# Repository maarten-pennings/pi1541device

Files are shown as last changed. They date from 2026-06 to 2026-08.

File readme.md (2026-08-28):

# Pi1541

My take on the _Pi1541_, the cycle exact Commodore 1541 disk drive emulator that runs on a Raspberry Pi.

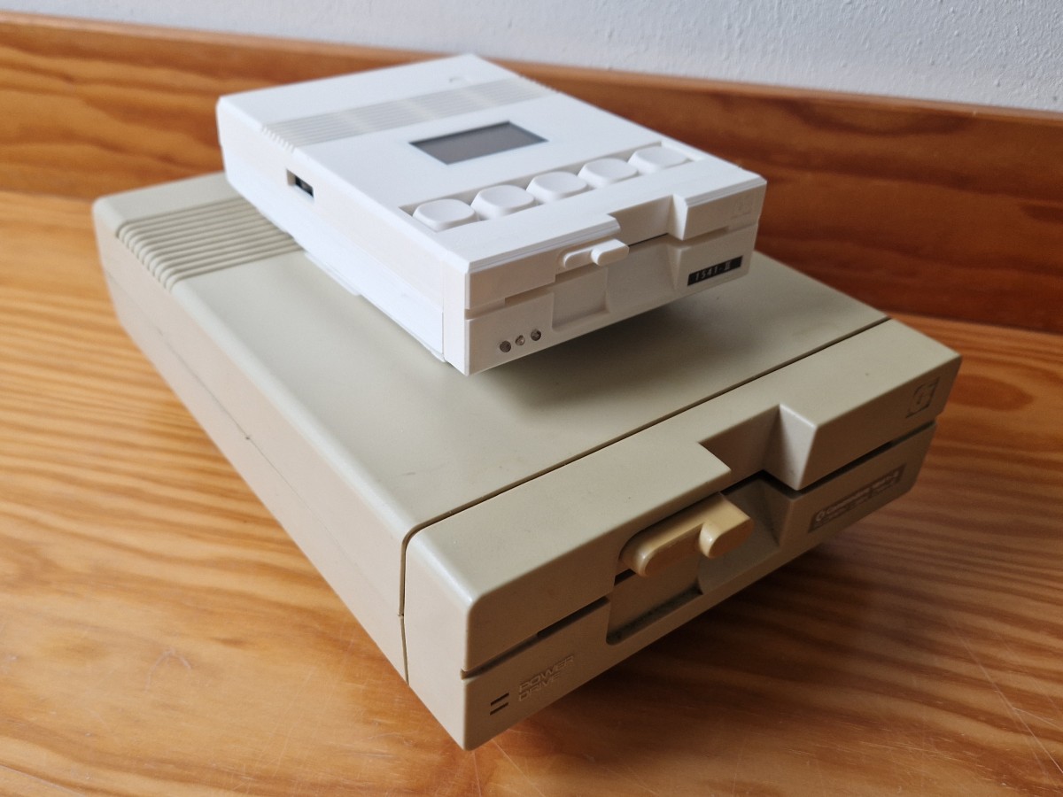
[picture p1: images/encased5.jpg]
My Pi1541 on top of an original
> 
> _My Commodore 1541-II disk drive (bottom) with my Pi1541 replica on top._

## Introduction

The _Commodore 1541_ is a 5.25-inch floppy disk drive.
It was _the_ solution for file storage when working with Commodore 64 (C64). 
Over the decades the drives and floppy disks degraded.
Various disk drive replacements where developed. 
One of them is the _Pi1541_, the topic of this repo.

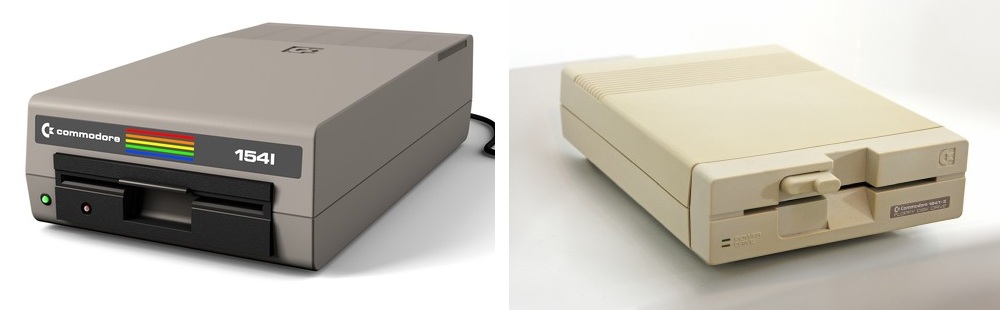
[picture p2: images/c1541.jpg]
C1541
> 
>
> _Commodore 1541 from [Commodore online museum](https://cbmmuseum.kuto.de/floppy_vc1541.html)_
> _and later model (1541-ii) from [Wikipedia](https://en.wikipedia.org/wiki/Commodore_1541)_

An important predecessors of the Pi1541 was the 
[SD2IEC](https://www.c64-wiki.com/wiki/SD2IEC). The SD2IEC 
contains an ATmega644 micro controller from Atmel that 
translates Commodore serial bus (IEC) commands into FAT 
file system operations on the SD card. This allows the C64 
to access files on an SD card.

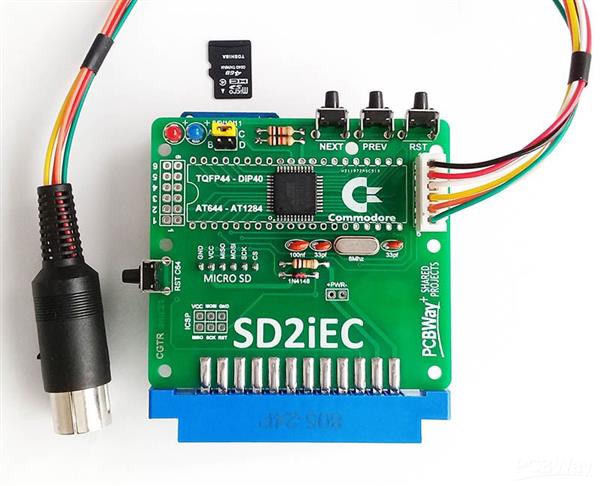
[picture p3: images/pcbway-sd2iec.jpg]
SD2IEC
> 
>
> _Example SD2IEC project from [PCBWAY](https://www.pcbway.com/project/shareproject/SD2iEC_COMMODORE_64_DISK_DRIVE_EMULATOR_POWERED_from_USER_PORT_MICRO_SD_VERSI_c56a9f83.html)_

The SD2IEC is low-cost and capable of storing about 25000 floppies
(of 170 kByte each) on a 4GB SD card. It is small and can be powered 
by the C64 itself (usually via the user port). 
The big drawback is that while the SD2IEC is compatible
with the _file level commands_, it cannot handle the _programming commands_ 
given via the secondary channel 15.

Unfortunately, due to the low-speed of the 1541, many commercial games, demos, 
and developer cartridges come with their own fast loaders. Part of a fast loader 
is software that is uploaded to the 1541 drive (which is a 6502 based 
computer on its own) via the above mentioned programming commands. 
The SD2IEC cannot run that uploaded software.
This results in low software compatibility: a large portion of the C64 
applications (games) will not load from an SD2IEC.

The Pi1541, developed by Steve White, solves this. Instead of an _ATmega644_ micro 
controller, it uses a more powerful _Raspberry Pi_ and a simple add-on (a so-called "HAT"). 
The Pi is powerful enough to provide a cycle-exact hardware emulation of the real 
Commodore 1541 drive. It emulates the drive's internal 6502 CPU, the RAM, 
and the VIA chips down to the exact clock cycle. You even need to download the 
original Commodore ROM image of the 1541 to "program" this virtual 6502.

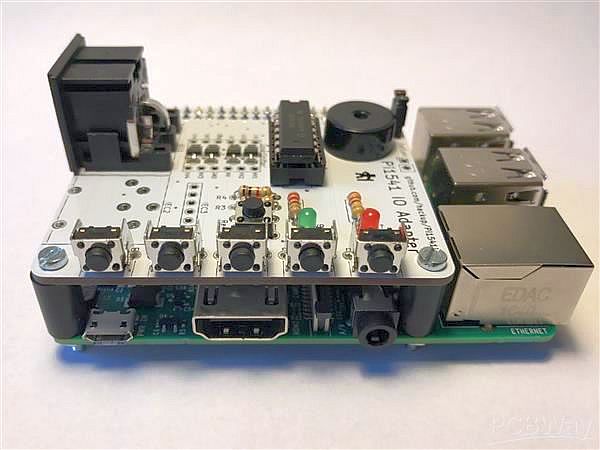
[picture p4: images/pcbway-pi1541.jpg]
Pi1541
> 
>
> _Example Pi1541 project from [PCBWAY](https://www.pcbway.com/project/shareproject/Pi1541_IO_Adapter__Rev_2.html)_

This solution provides near 100% compatibility because it behaves exactly 
like the original drive. It supports complex copy protections and almost every 
fast loader ever written (e.g., JiffyDOS, Final Cartridge III).

Steve White wrote a "bare metal" application on the Pi. This means his 
emulator does not run under Raspberry Pi OS (Linux) but directly on the 
_Broadcom BCM2837B0_. This results in fast booting, and carefree switching off 
the power. On the down side, the Pi1541 is more expensive than the SD2IEC due to the 
Raspberry Pi board; it is a bit bigger physically; and needs (more) external power.
But most believe these down sides are well compensated by the extra compatibility.

## Concepts

This section explains the key concepts when working with the Pi1541: 
current working directory, three categories of commands, the new `CD` command, 
mounting a `.d64` file as virtual floppy, the problem with the programming commands, 
and finally _browse mode_ and _emulation mode_.

### Current working directory

The Pi1541 contains an SD card, and it maintains a notion of the 
_current working directory_ on that SD card. Its firmware bridges the 
commands that come from the C64 (over the IEC bus) to the FAT file system 
on the SD card. 

It does understand the _high level commands_ such as 
`SAVE "MYGAME"`, `LOAD "MYGAME"`, or `LOAD "$"`. The `SAVE "MYGAME"` creates a file `MYGAME` 
on the SD card, in the current working directory. Similarly `LOAD "MYGAME"` 
reads the file `MYGAME` from the current working directory and sends it back 
to the C64 over the IEC bus. It will be no surprise that `LOAD "$"` reads 
the current working directory and sends that back to the C64.

### Commands 

If you are more than a casual user of the C64 and the 1541 drive, 
you will know that next to those high level commands there are more 
_advanced commands_ that a 1541 will understand. 
The Pi1541 also emulates those. For example `OPEN 1,8,15,"S0:MYGAME":CLOSE 1` 
scratches (deletes) the file `MYGAME` from the current working directory, 
and `OPEN 1,8,15,"R0:YOURGAME=MYGAME":CLOSE 1` renames `MYGAME` to `YOURGAME`.

Recall that the DOS (disk operating system) was not part of the C64 
(would have taken too much memory), rather it was baked into the 1541 itself.
What is part of the C64, is setting up a "data pipe" (open a file) and send 
the (textual) command over that pipe. The 1541 receives the textual command,
parses it and executes it. That is the reason we have advanced commands 
(eg see [c64-wiki](https://www.c64-wiki.com/wiki/Commodore_1541#Disk_Drive_Commands)).

### CD 

You might be wondering how to _change_ the current working directory. 
The developers of the SD2IEC added an advanced command: `CD`. For example 
`OPEN 1,8,15,"CD:SUBDIR":CLOSE 1` changes the current working directory 
to subdirectory `SUBDIR` assuming that subdirectory exists in the current 
working directory. The command `OPEN 1,8,15,"CD:←":CLOSE 1` (the `←` being 
the key in the upper left corner on the C64 keyboard) moves back to the 
parent directory. No idea why they did not pick the standard `..` instead 
of the rather obscure `←`. Next to `CD`, related advanced commands were 
added: `MD` to make a directory and `RD` to remove an (empty) directory.

Of course the C64 doesn't know about the `CD` command, but you as operator 
can issue it and the new directory feels like a new disk to the C64. 
Typically the SD2IEC and the Pi1541 also come with a file browser (`FB64`) running on the C64. 
This browser does know the `CD` command and allows easy navigation through 
the file system on the SD card.

### Mounting a virtual floppy 

There is one more important concept. In the C64 retro community, floppy disks are ripped 
to a single file. They have the extension `.d64` and are useable as virtual disk in tools 
like VICE, the C64 Ultimate, and also the SD2IEC and Pi1541. 

SD2IEC and Pi1541 treat `.d64` files a bit like 
Windows treats `.zip` files. It is one _file_, but you can `CD` 
into it, and that "unzipped" `.d64` file is then the "mounted" _directory_. All 
high level commands (`LOAD`) work on the mounted floppy, and so do all 
advanced commands (`S0:MYGAME`). Even `OPEN 1,8,15,"CD:←":CLOSE 1` works;
it unmounts the `.d64` virtual floppy and switches to its parent directory.
Of course `OPEN 1,8,15,"CD:SUBDIR":CLOSE 1` does not work in the mounted `.d64` because
`.d64` files are supposed to be ripped 1541 disks, and the 1541 did not have a notion 
of subdirectories.

### Programming commands 

We should realize that the firmware (of SD2IEC and Pi1541) sees the high 
level and advanced commands come in via the IEC bus. It needs to parse and 
understand the commands, and then execute them. That is the task for the software written 
by the programmers of those two devices. That is development work.

Unfortunately, next to the high level and advanced commands there is a third 
category, the _programming commands_. Chapter 8 of the 1541 
[user manual](https://www.zimmers.net/anonftp/pub/cbm/manuals/drives/1541_Users_Guide.pdf) 
introduces these with the text "The expert programmer can actually design routines 
that reside and operate on the disk controller". This is with commands such as `M-W` 
(memory write), `M-R` (memory read), and `M-E` (memory execute). Here is 
an example from the manual (recall that `RTS` has opcode 0x60 or 96 decimal).

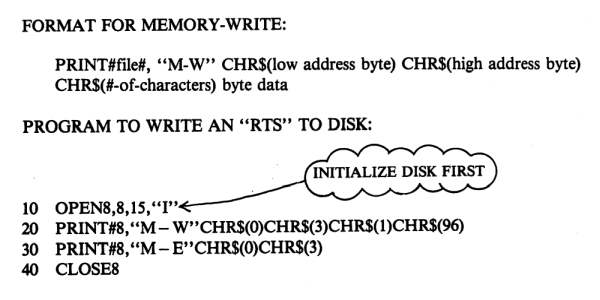
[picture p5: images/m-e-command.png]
memory execute example
> 
>
> _Example of programming commands from the 
> [user manual](https://www.zimmers.net/anonftp/pub/cbm/manuals/drives/1541_Users_Guide.pdf)_

The above 1-byte "program" is written by the C64 into the memory of the 1541 drive 
(to address 0x0300), and then the C64 gives a command to execute from 0x0300. The 1541 
starts executing there, finds opcode 96 (RTS), returns, and stops executing the 
program. I made a more elaborate example 
[blinky1541](https://github.com/maarten-pennings/C64howto/tree/main/blinky1541).
Anyhow, these programming commands of the 1541 are the mechanism used by fast loaders.

### Browse mode versus emulation mode

So far SD2IEC and Pi1541 are very similar. Now we come to an important difference.
The SD2IEC does _not_ implement the programming commands, but Pi1541 _does_.
In a clever way.

The Pi1541 has two modes. The developer, Steve White, calls them _browse mode_ and
_emulation mode_. We could say that the SD2IEC only supports browse mode, and Pi1541 
supports both. When the Pi1541 starts, it is in browse mode. In browse mode, the 
firmware from Steve runs. This firmware implements the high level and advanced 
commands _including the `CD` command_. This allows all existing tools to 
browse all files on the SD card. As soon as a command comes in that `CD`s into 
a virtual floppy disk (a `.d64` file) - I called this "mounting the floppy" above - the Pi1541 
switches to emulation mode. In emulation mode the Raspberry Pi _emulates the 1541_.

The emulation is serious. A real 1541 contains a 6502,
RAM, ROM, and VIAs. The Pi1541 emulates all of those, to the clock cycle. 
Timing of pulses on the IEC bus matters to the C64. What code does the emulated 
6502 run? It runs the original 1541 ROM from Commodore that you have to download 
and put on the SD card - Steve can't do that due to licensing reasons. As a consequence 
all `M-W` and `M-E` commands are working since they are implemented by that 1541 rom. 
Software that is uploaded and executed this way, by the fast loaders, also just works; 
it doesn't know the 1541 is emulated.

In emulation mode, an `OPEN 1,8,15,"CD:←":CLOSE 1` is intercepted, unmounts the `.d64`, 
sets the working directory to the parent, and switches back to browse mode. 

It is important for a user to know about these two modes, and to know which one is 
running when. For example, the advanced command `OPEN 1,8,15,"N0:DISKNAME,DN":CLOSE 1`
(recall `N` stands for `NEW` meaning "format") in _browse_ mode just _creates_ a 
new, empty, formatted virtual floppy image with the name `DISKNAME.d64` on the SD card. 
If you give the same command in emulation mode, the original 1541 firmware kicks in, 
and it will happily wipe (format) the entire mounted `.d64` virtual floppy.

> There is another, arguably more important, caveat to be aware of. 
> Writes to a .d64 image (e.g. `SAVE "MYPROG"`) in emulation mode are not 
> written-through to the SD card. All updates are in the Pi's RAM. 
> You _must unmount_ the virtual floppy (with `"CD:←"` or by pressing 
> the ESC key on the Pi1541). Only then the new content is written to 
> the FAT file system on the SD card.

### My additions

Mostly for fun, I have made a couple of additions to Steve's firmware. The `CD:subdir` command 
goes one subdirectory down, and `CD:←` goes one up. For some reason the `CD://` did not 
work. It is supposed to go to the root directory (yes with two slashes, something to 
do with multiple volumes). I fixed it. Secondly, I was missing a `pwd` command (print 
working directory). I added a `LOAD "$$"` command (I call it "sysinfo") that does that. 
I added both features in 
[v1.27](https://github.com/maarten-pennings/Pi1541#additions-in-this-fork).

## Real life operation

You might be wondering how the Pi1541 works in real life. 

You can operate the device completely from the C64:
you can do the `CD` commands combined with `LOAD "$"` by hand,
or let `FB64` do them for you.

But the Raspberry Pi can also be connected to a full keyboard and HDMI screen. 
The HDMI screen will always show the current directory and its contents (files and 
subdirectories), also when it is changed with `CD` (or `FB64` doing `CD`s).
It is also possible to change the current directory with a keyboard 
connected to the Raspberry Pi (via USB). 

There is a third option. We can connect an OLED and five buttons 
(Next, Previous, Select, Escape and Insert) to the Pi. 
The OLED will also always show the current directory 
(in sync with the HDMI screen), and the buttons also allow browsing 
(just like the USB keyboard).

Three methods, always in sync.

Oh, and in [v1.25](https://github.com/maarten-pennings/Pi1541#additions-in-this-fork)
I added support for a bigger (1.54") OLED, making it easier to read from a distance.

The table below shows the functions of the five buttons. 
When holding the Insert key for a longer time, it acts as a shift key for the 
other four. It changes the device number as shown in the "Drive" column.
The swaplist is there to support large programs that use multiple floppies 
that need to be swapped during the run-time of the program.
Finally, note that the Escape key triggering an unmount is a feature of my v1.27 firmware;
originally Select did the unmount.

| Button | Description | Browse mode | Emulation mode |Drive |
|:---|:---|:---|:---|:----:|
| SEL | Select | Change to sub dir (or mount) | - | 8 |
| PRV | Previous | Select previous dir | Previous in swaplist | 9 |
| NXT | Next | Select next dir | Next in swaplist | 10 |
| ESC | Escape | Change to parent dir | Unmount | 11 |
| INS | Insert | Insert .d64 file in swaplist | - | shift|

## SD card

Preparing the SD card for the Raspberry Pi means merging files from different sources.

There are three sources:

- The GitHub repo from the Raspberry Pi foundation supplies the Pi's bootloader files.
- The GitHub repo from Steve (or me) supplies the Pi1541 firmware and its config file (and a filebrowser)
- Some internet site supplies the Commodore 1541-II firmware and the C64 font roms (used on the OLED), and maybe the game _Ghosts'n Goblins Arcade_ to test the hex inverter quality.

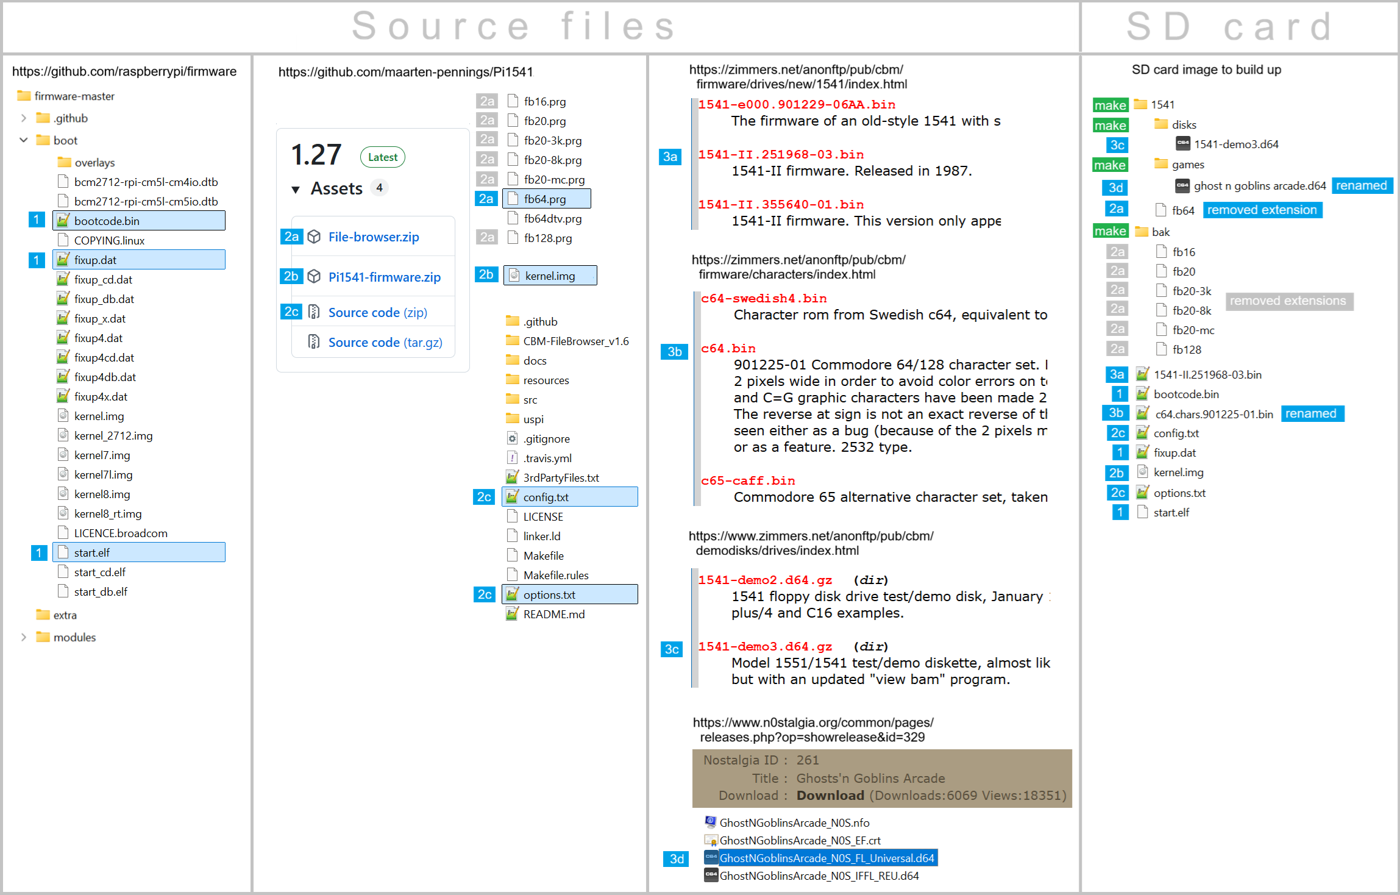
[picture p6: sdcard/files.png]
sdcard creation
> 
> _The three sources of files to be combined into the SD card image._

This repo includes a prepackaged [SD card image](sdcard/pi1541sdcard.zip).
Alternatively, check the [sdcard](sdcard) subdirectory for a do-it-yourself 
and some technical background details.

Note that a `.prg` file in a sub directory (not inside a `.d64`) 
will typically be loaded with a `LOAD` command passing the _filename_ as 
used on the SD card. It is advised to restrict the filename to
characters available on the C64, e.g. no `_`, but also no _capitals_.
Personally, I also leave out the `.prg` extension; 
`LOAD "HELLO",8` feels more C64 like than `LOAD "HELLO.PRG",8`.
Similar considerations (uppercase, underscores) apply to naming subdirectories.

## My design

I wanted a Pi1541 for my C64.
My goal was to make a device that resembles a real drive.

I wanted it fully featured: local keys and display, two IEC connectors 
(daisy chainable IEC like the real drives), physical access to the SD card, a reset button, 
power and activity LED, an LED to show data line status, drive sound emulation,
access for USB power and access to HDMI out. 

I wanted it easy to operate: 
big buttons ([Cherry keys](https://nl.aliexpress.com/item/1005012280948086.html)), 
big display (biggest OLED). I wanted the replica to roughly have the same aspect ratios as the original 
drive (the 1541-II is 240×180×70 mm³). This posed a problem for the Cherry keys; 
they are relatively tall, so they need to be mounted on the "floor" PCB,
the PCB that I had to design. 

My PCB would normally be the HAT ("Hardware Attached on Top") for the Raspberry Pi,
but due to the Cherry keys I needed to turn them upside down. My PCB is 
the HAB ("Hardware Attached on Bottom") which holds the Cherry keys and the IEC
connectors, and the Pi, upside down. I did want an (OLED) display, 
so that needed to be above the Pi.

This is a sketch of how I envisioned the topology.

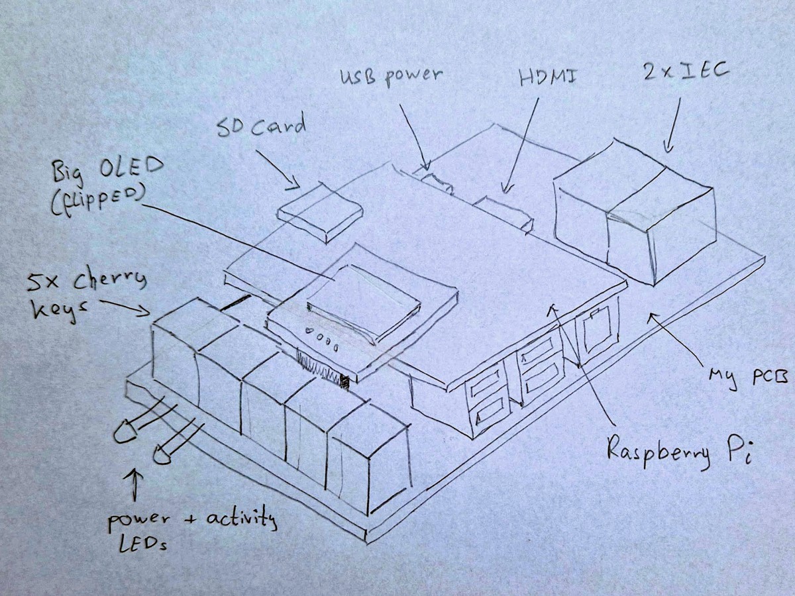
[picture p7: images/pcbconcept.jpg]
Pi1541 concept sketch
> 
> _Sketching the placement of the key components_

From front to back we find:

- LEDs on the front (for the front panel).
- Next the Cherry keys on floor PCB.
- High rising pin header for a flipped OLED,  
  flipped in the sense that the top pixel row of the OLED is now facing the Cherry keys.
- After that we have the upside-down Raspberry Pi, SD card nicely accessible from the side.
- At the back we have the two IEC DIN connectors also on the floor PCB.
- Biggest problem is that the power (and HDMI) are not flush with the backside.
  I mitigated that by using an 
  [USB-C to micro USB converter](https://nl.aliexpress.com/item/1005009140380972.html), 
  which not only converts to the newer USB-C, it also happens to bring the USB connector 
  more to the back.

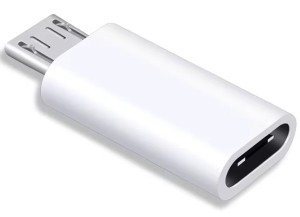
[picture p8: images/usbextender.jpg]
USB extender
> 
> _USB-C to micro USB converter_

### Hardware

The simplest schematics Steve White offers is a Raspberry Pi and a level shifter
("Option A"). I based my design on [Option B](https://cbm-pi1541.firebaseapp.com/#:~:text=are%20all%20optional.-,Option%20B,-This%20option%20uses) of Steve.
This is for devices with two IECs. The Pi is not capable of sourcing enough current
for the second "outgoing" IEC bus, so a tri-state hex inverter IC (7406) 
is used as bus driver. Steve warns that this driver IC needs to be selected carefully.

> [Ghosts'n Goblins Arcade](https://www.n0stalgia.org/common/pages/releases.php?op=showrelease&id=329) 
> can be used to test the capability of your hex inverter.
> If the title screen is corrupt then please substitute the hex inverter IC for a genuine branded version.

It was a bit of a puzzle how to connect the peripherals to the Pi.
The IEC wiring is different between Option A and B.
The local buttons, activity LED and buzzer are shown in Steve's schematics, but not the OLED.
I started with a breadboard.

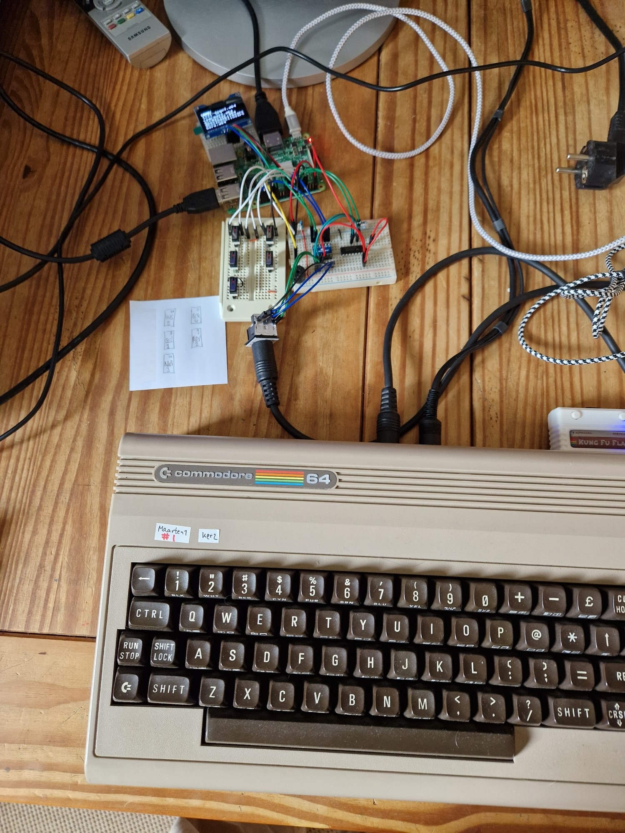
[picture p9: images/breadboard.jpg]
Breadboard
> 
> _Option B prototype on a breadboard_

I used the biggest 128×64 OLED module I had in stock.
It is [1.54 inch](https://nl.aliexpress.com/item/1005006579037427.html), not the more
common 1.3" neither the even smaller 0.96".
Since the various OLEDs modules tend to vary in the order of the four pins (SCL, SDA, VCC, GND), 
I added a second header (J3 and J4) and solder jumpers in between.
This allows me to solder patch wires if I have an OLED with different pin order.

I did add a (RESET) button on the IEC reset line. Pressing it resets the Pi1541 as well 
as the C64. Not sure if that is useful. I considered, but did not add 
a button that resets just the Pi; the Pi does have two pads for that.

I did add a beeper. 
I believe I have a [passive](https://www.circuitbasics.com/what-is-a-buzzer/) one.
These require a waveform to be generated by the micro controller (Pi in my case);
they are low end "speakers for audio". Active beepers on the other hand only need power;
they have a built-in oscillator and produce single frequency beeps.
Warning: the emulated drive sound is much lower quality then what VICE offers; 
I believe it is basically a buzz when the drive head moves a track.

I added a red LED for power and green for the activity LED.
This is the color scheme used in the 1541-II. The original 1541 had the colors swapped.

> The latest firmware (1.24) of Steve has a regression: the Activity LED is not working.
> I fixed that in my [fork](https://github.com/maarten-pennings/Pi1541).

My final addition was a blue LED that is on the IEC _data_ line.
We see it flicker when data is transmitted.

I ordered my PCBs at [JLCPCB](https://jlcpcb.com/DMP); 5 PCBs for €10.44 including 
shipping, arrived in 10 days.

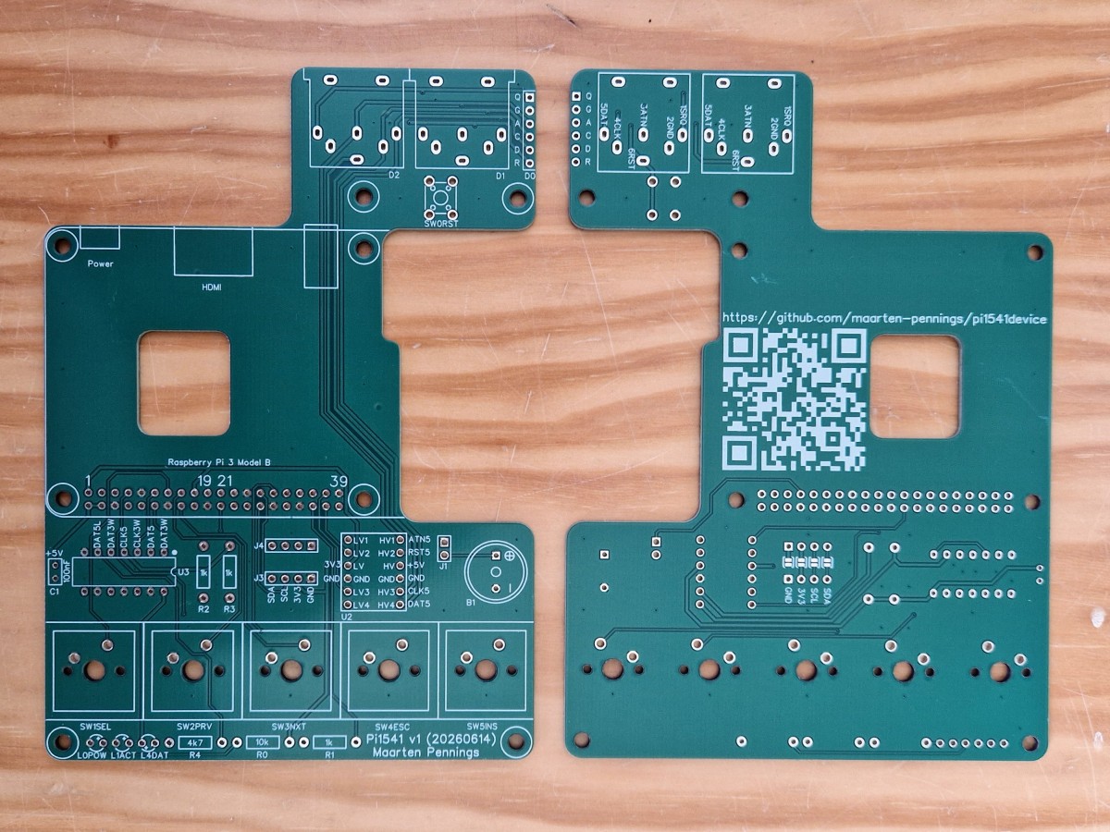
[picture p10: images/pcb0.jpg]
PCB front and back
> 
> _Bare PCB (front and back)_

A photo of the assembled PCB, including some 3D printed parts like the OLED holder
and standoffs.

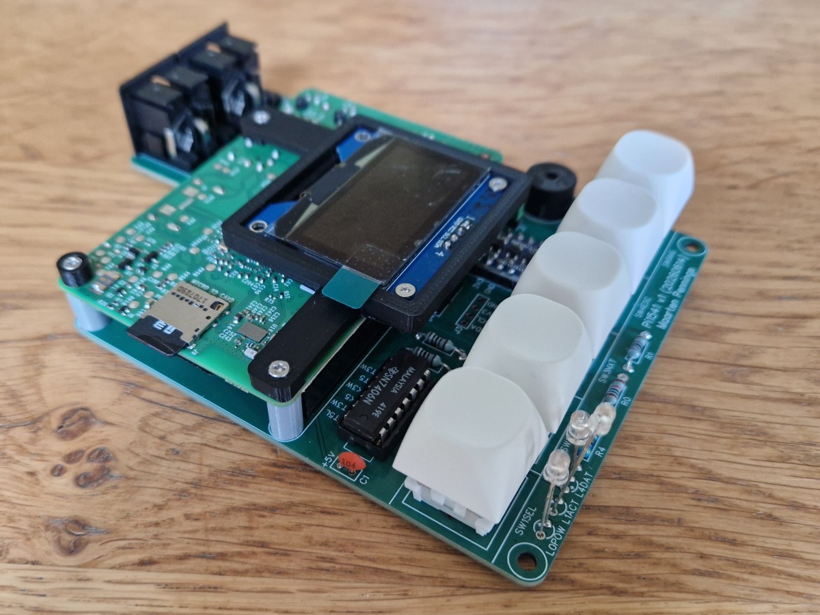
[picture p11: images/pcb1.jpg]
Assembled PCB
> 
> _Assembled PCB_

For a more extensive gallery and the design files itself, see directory [PCB](pcb).

### Case

I wanted my case to look like the real drive.
I picked the 1541-II, because I have that one and because it is the firmware I'm using.

I tried to copy the key features of the original: its ventilation slits at the top cover
and in the foot, the chamfered foot, and of course the front panel. 
I designed at about 60% scale: from 240×180×70 mm³ to 150×105×42 mm³.
In total there are four exterior parts: top, bottom, foot and front.

For assembly of the PCBs I 3D printed standoffs.
The Raspberry Pi is attached to my PCB using four M2 
[nuts and bolts](https://nl.aliexpress.com/item/32946954901.html) 
with 3D printed standoffs between my PCB and the Pi.
At the top of the Pi the M2 screws run through the OLED holder 
(so the stack is: nut, my pcb, standoff, Pi PCB, OLED holder, bolt head).

The OLED is fixed with two M2 [nuts and bolts](https://nl.aliexpress.com/item/32946954901.html)
to the OLED holder

For assembly of the cases I use M2 
[brass inserts](https://nl.aliexpress.com/item/1005009955547831.html) in 
the front panel (2 pieces) and in the top cover (5 pieces); with matching M2 
[bolts](https://nl.aliexpress.com/item/32946954901.html)
of different length. The foot is screwed to the bottom part with three M3 bolts and nuts.
I glued rubber feet at the bottom.

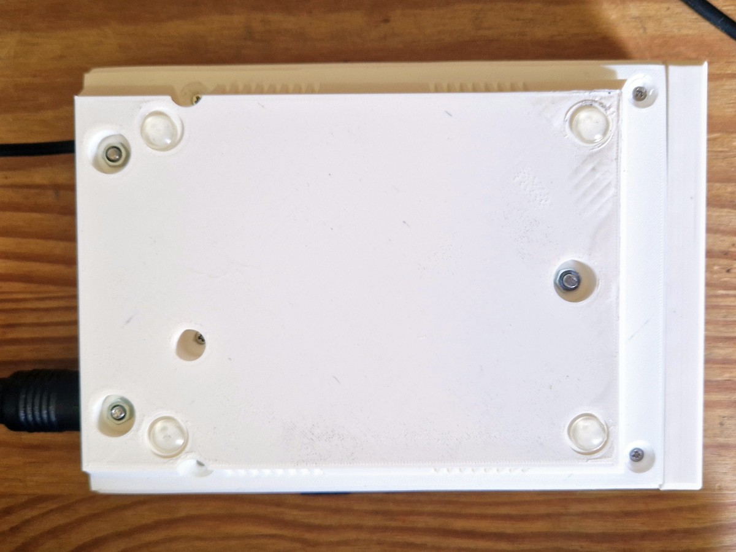
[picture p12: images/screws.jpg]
Screws at the bottom side
> 
> _Casing shown from bottom side (screws, rubber feet)_

One laborious task is to solder wires to each of the three LEDs, solder them
to the LED pads on the PCB, and mount the LEDs in the front panel.

I protected the OLED by inserting a 
[plexiglass](https://nl.aliexpress.com/item/1005011620310692.html) 
rectangle in the top cover. There was no need to glue; the OLED presses it
in the recess of the top cover.

Next to the four exterior 3D printed parts there are also four interior parts: 
OLED holder, reset switch extender, standoffs (four, one for each corner of the Pi), 
and one small standoff for the corner that is not covered by the OLED holder.

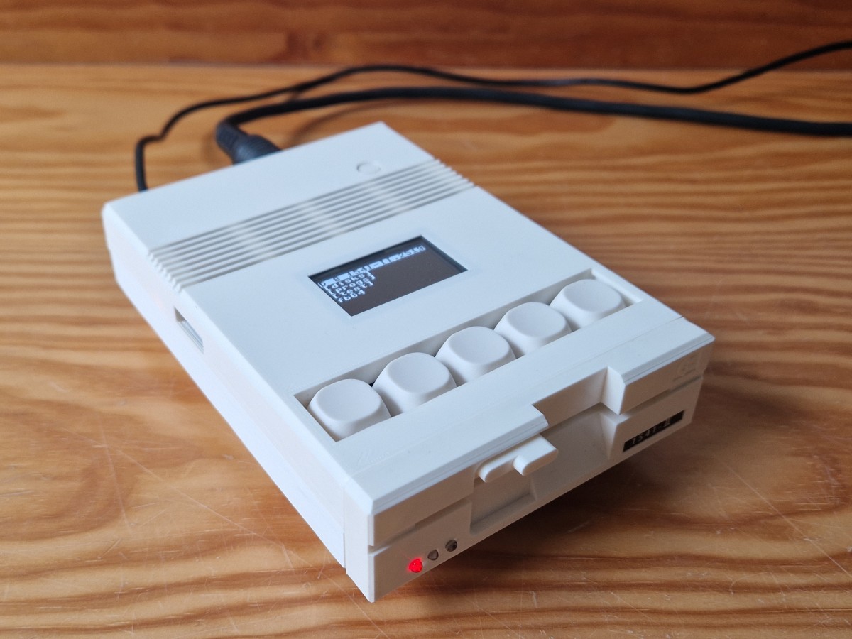
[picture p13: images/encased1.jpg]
Fully encased
> 
> _My Pi1541 fully encased_

I designed all 3D printed parts myself in 
[Fusion 360](https://www.autodesk.com/nl/products/fusion-360).
See directory [case](case) for details, STL files and gallery.

### Software

The SD card in the Raspberry Pi hosts several files, one of them is the Pi1541 firmware.
That is developed by Steve White, see his [GitHub repo](https://github.com/pi1541/Pi1541).

I had one real problem: my big 1.54 OLED has a driver IC that was not fully compatible 
with the ones that Steve's firmware already supported. I also 
[found out](https://github.com/pi1541/Pi1541/issues/206#issuecomment-1162708867) 
that my activity LED was not working due to a regression in the firmware 1.24.
I [forked](https://github.com/maarten-pennings/Pi1541) Steve's repo and made 
my own release 1.25 with these two fixes.

I did make another small change. It did not feel natural to 
me to leave emulation mode by pressing ENTER/SELECT, I changed that to ESCAPE.
See release v1.26.

Once I started playing with the advanced disk commands I missed two features.
One was to CD to the root. The other one was a pwd command (print working directory).
My release V1.27 adds support for `CD://`. The pwd command was implemented 
by adding a virtual file "sysinfo". The command `LOAD "$$"` and then `LIST` shows
some system information of the Pi1541.

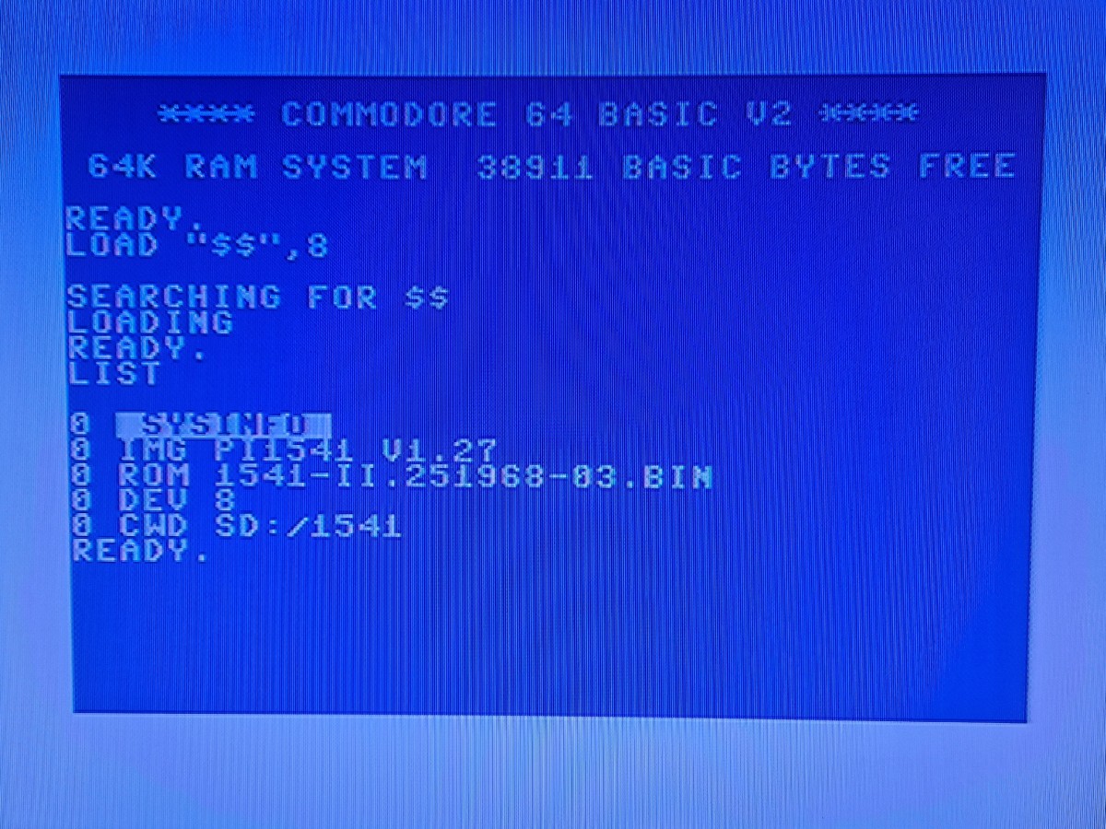
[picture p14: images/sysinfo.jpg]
sysinfo
> 
> _The sysinfo command in action_

See my other [repo](https://github.com/maarten-pennings/Pi1541) for the changes I made.
You find [sources](https://github.com/maarten-pennings/Pi1541/tree/master/src), 
[binary releases](https://github.com/maarten-pennings/Pi1541/releases) and 
even a [workflow](https://github.com/maarten-pennings/Pi1541/blob/master/.github/workflows/build-pi1541-firmware.yaml) for building the firmware in the GitHub cloud.

## Links

- Prepackaged [SD card image](pi1541sdcard.zip).
- The official [documentation](https://cbm-pi1541.firebaseapp.com/) by Steve White.
- The GitHub [repo](https://github.com/pi1541/Pi1541) with the firmware from Steve White, 
  or my [fork](https://github.com/maarten-pennings/Pi1541).
- Older versions of [pi1541](https://cbm-pi1541.firebaseapp.com/whatsnew.html#oldversions.:~:text=the%20wrong%20folder.-,Old%20Versions,-.) firmware,
  or my [newer](https://github.com/maarten-pennings/Pi1541/releases).
- A Pi1541 [manual](https://www.combitronics.nl/download/pi1541%20Manual.pdf) by Michael Long.
- For commands (like `cd`) see the GitHub
  [repo](https://github.com/pi1541/Pi1541/blob/master/docs/IEC%20Commands.md) or
  the SD2IEC [user manual](https://c64os.com/post/sd2iecdocumentation) on C64OS.
- Zimmers has [1541 roms](https://zimmers.net/anonftp/pub/cbm/firmware/drives/new/1541/index.html), [character roms](https://zimmers.net/anonftp/pub/cbm/firmware/characters/index.html)
  or [demo disks](https://zimmers.net/anonftp/pub/cbm/demodisks/drives/index.html).

(end)

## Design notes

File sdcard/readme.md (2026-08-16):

# SD card

This page described in more detailed how to create an SD card image.
It also includes technical details of why each file is needed.

## Setup SD card

Preparing the SD card for the Raspberry Pi means merging files from different sources.

There are three sources:

- The [GitHub from the Raspberry Pi foundation](https://github.com/raspberrypi/firmware) 
  supplies the Pi's bootloader files.

- The GitHub [repo](https://github.com/pi1541/Pi1541) with the firmware from Steve White, 
  or my [fork](https://github.com/maarten-pennings/Pi1541) supplies the Pi1541 firmware and its
  options file and a filebrowser.

- Zimmers for [1541 roms](https://zimmers.net/anonftp/pub/cbm/firmware/drives/new/1541/index.html), [character roms](https://zimmers.net/anonftp/pub/cbm/firmware/characters/index.html)
  or [demo disks](https://zimmers.net/anonftp/pub/cbm/demodisks/drives/index.html).
  Nostalgia supplies [Ghosts'n Goblins Arcade](https://www.n0stalgia.org/common/pages/releases.php?op=showrelease&id=329) to to test the hex inverter quality.

The infographic below shows the required contents of the SD card (right side, blue numbered tags);
the left three columns show where to find each item (same blue numbered tags).

sdcard creation

This repo includes a prepackaged [SD card image](pi1541sdcard.zip);
download it, unzip it and place in the root of a FAT formatted SD card 
(the file `kernel.img` must be in the root of the SD card).

> WARNING the SD card image has my kernel V1.27.

> WARNING every kernel needs to be configured via `options.txt`.
> Configuration includes (but is not limited to) which OLED is on your PCB, 
> which GPIO pins do the buttons use, what is the name of the file that 
> contains the drive rom, do you want sound.

> WARNING the `options.txt` on the SD card matches my PCB and my choices.

## Background

This section explains why all those files are needed.
Feel free to skip.

### Raspberry Pi foundation

It seems that on a Raspberry Pi (up to version 3), the GPU takes care of the boot process.
When the Raspberry Pi powers on, the bootloader burned directly into the hardware (ROM) wakes up. 
It only knows how to look for a file named `bootcode.bin` on an SD card with FAT16 or FAT32.
We get boot files from [raspberrypi's GitHub](https://github.com/raspberrypi/firmware).

- The Bootloader `bootcode.bin` (50 kbyte). 
  This is the first code the Raspberry Pi’s GPU reads from the SD card (into the GPU's cache).
  It initializes the memory and prepares the system to load the GPU firmware.

- The GPU firmware `start.elf` (3 Mbyte) is the "operating system" for the GPU. 
  It reads `config.txt`, sets up the clocks, configures the display/HDMI, splits the RAM between the GPU and the CPU. 
  Finally, it loads your bare-metal binary `kernel.img` into RAM, and releases the ARM CPU from reset so it starts executing code.

- The memory map `fixup.dat` (7 kbyte) is a companion to `start.elf`.
  It contains configuration data partitioning the RAM between the GPU and the CPU, read by `start.elf`.

### Pi1541 firmware

We get the real firmware from [Pi1541.zip](https://cbm-pi1541.firebaseapp.com/Pi1541.zip) or my [fork](https://github.com/maarten-pennings/Pi1541).

- The firmware `kernel.img` (500 kbyte) is the default file the GPU (`start.elf`) 
  looks for to start the main processor (ARM CPU). This name usually points to the Linux kernel but it can 
  be any compiled binary. The _Pi1541_ is a bare metal firmware. This means that the code runs
  directly on the hardware without an underlying operating system (no scheduler, no file system).

  Steve's latest greatest (v1.24) has some flaws like activity LED not working. 
  If you need the activity LED take an older versions at the bottom of this 
  [page](https://cbm-pi1541.firebaseapp.com/whatsnew.html#oldversions.:~:text=the%20wrong%20folder.-,Old%20Versions,-.).
  Alternatively, take  my [v1.27r](https://github.com/maarten-pennings/Pi1541).

- Configuration `config.txt` (41 byte) is read by `start.elf` (the GPU firmware), not `kernel.img`.
  It contains two lines.
  - `kernel_address=0x1f00000`  
    By default, the Raspberry Pi loads the kernel at address 0x8000 but the Pi1541 code is compiled for another address.
  - `force_turbo=1`  
    By default the Raspberry Pi clocks its CPU down when it is idle (dynamic frequency scaling). 
    This locks the CPU at its maximum rated speed constantly.
    The 1541 disk drive is a "real-time" device, it communicates with the C64 using fixed pulse widths.
    If the Pi would clock down, the pulse timings will shift, leading to communication errors.

- User options `options.txt` (6 kbyte) is written specifically for the Pi1541 
  emulator (which buttons, OLED type, how many IEC connectors, etc).

- The directory `1541` is the root directory for the "disks" served by the firmware.
  It contains (will later contain) disk images (`.d64`) files, 
  but it may also contain `PRG` files, i.e. C64 (or VIC-20, or ...) binaries 
  that the C64 can load directly from the Pi1541. 

  Since I only have a C64 I decided not to pollute my `1541` root directory with all 
  file browsers. I kept `fb64` and stored all others in `\bak`.

  I decided to remove the `.prg` extensions to make it more natural to load from C64
  (entering `LOAD"FB64",8` instead of `LOAD"FB64.PRG",8`). It is also wise to prevent 
  uppercase characters in `.prg` files on the SD card - they are hard to enter in C64.

### Commodore binaries

You need commodore binaries.
If you have VICE on your system, you already have them
Alternatively, download them from Zimmers: 
[drive roms](https://www.zimmers.net/anonftp/pub/cbm/firmware/drives/new/1541/index.html) 
or [font roms](https://zimmers.net/anonftp/pub/cbm/firmware/computers/c64/index.html)

- `1541-II.251968-03.bin`
  You need Commodore binaries that run on the disk drive.
  I kept it simple and just have one binary: the latest greatest
  one used in the 1541-II.
  You have to configure the rom name in `options.txt`.

- `c64.chars.901225-01.bin`
  A fun aspect is that the OLED can use the C64 font (you have to 
  configure this in `options.txt`). If you enable this you also 
  have to install the C64 font on the SD card.
  You have to configure the font name in `options.txt`.

- `1541-demo3.d64`
  To have something to start with, the demo disk that 
  came with the original 1541 is stored in `disk`.

- `ghost n goblins arcade.d64`
  Another d64 image, of a game.
  This game includes a time critical fast loader.
  It is used as a benchmark for your Pi1541 implementation.

### Other files

Place any `prg` or `d64` file in (any subdirectory of) the `1541` 
directory (which is in the root of the SD card).

(end)

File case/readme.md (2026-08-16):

# Case for the Pi1541

3D-printed parts for the Pi1541.

## Introduction

I designed several 3D-printed parts for my Pi1541.
I used these names: bottom, top, front and foot for the outside parts,
and OLED-holder, button-extender, standoff11hx6x3, standoff4hx6x2.5 for 
the inside parts.

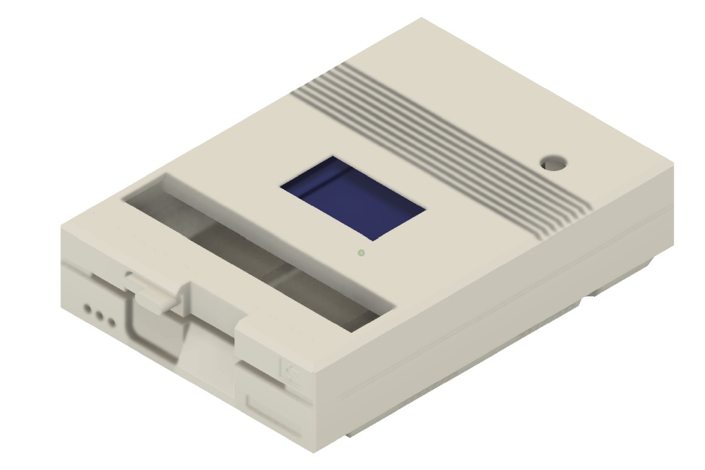
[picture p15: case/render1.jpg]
top/front view


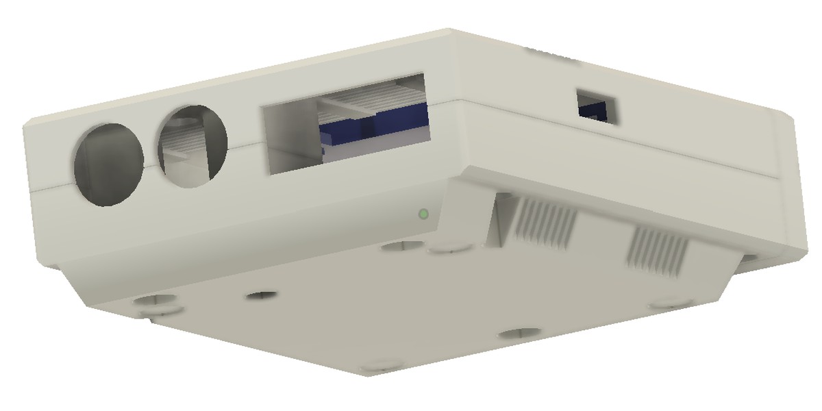
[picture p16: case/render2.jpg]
bottom/back view


## Outside

Here is an overview of the outside parts.

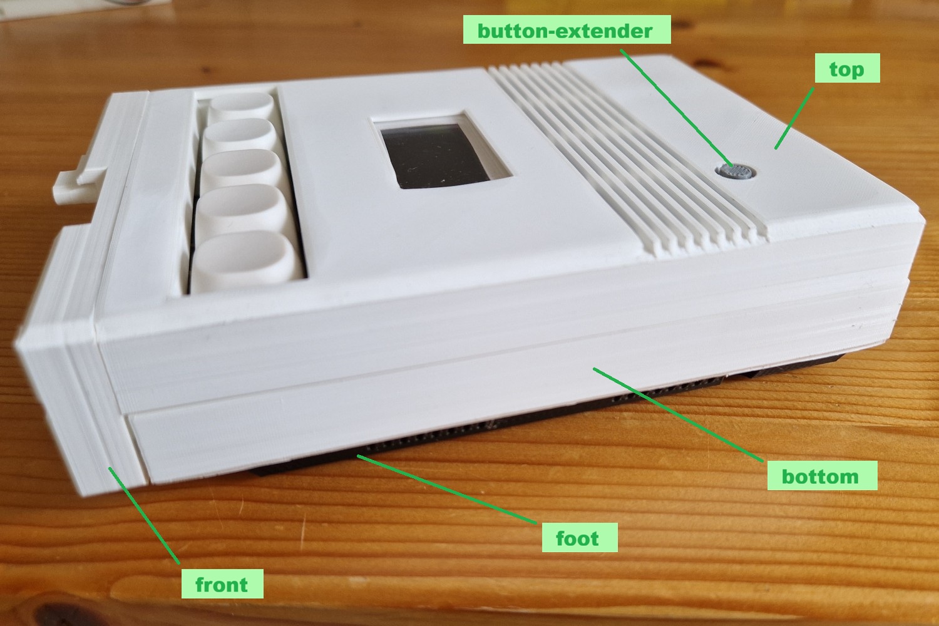
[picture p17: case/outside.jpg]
outside parts


- [bottom stl file](bottom.stl)  
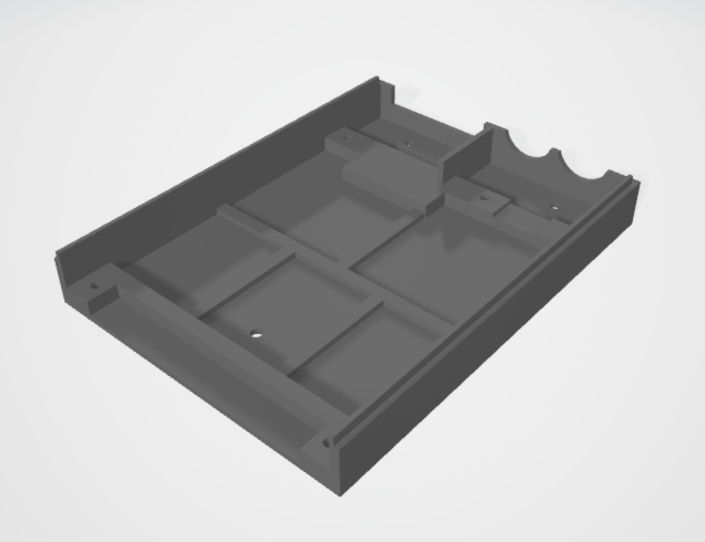
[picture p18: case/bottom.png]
bottom
  

- [top stl file](top.stl)  
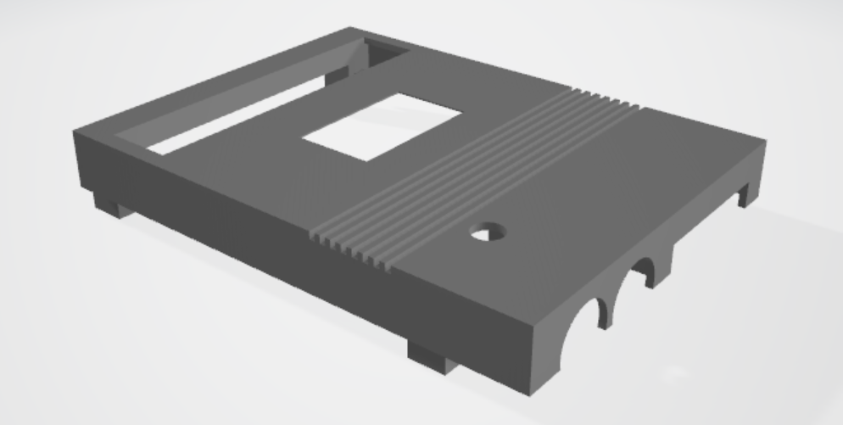
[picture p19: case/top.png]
top
  

- [front stl file](front.stl)  
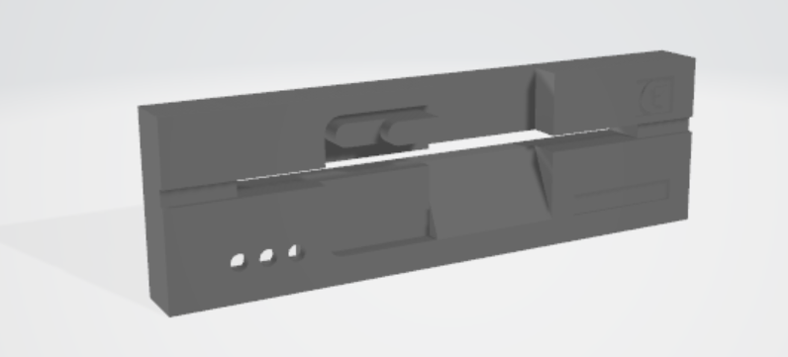
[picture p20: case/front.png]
front
  

- [foot stl file](foot.stl)  
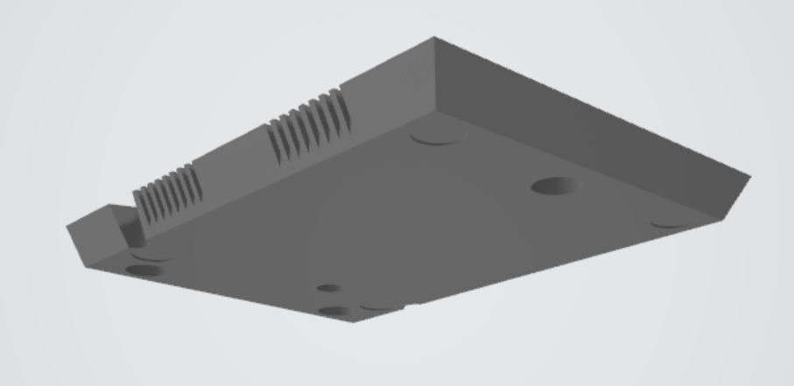
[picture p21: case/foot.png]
foot
  

## Inside

Here is an overview of the inside parts.

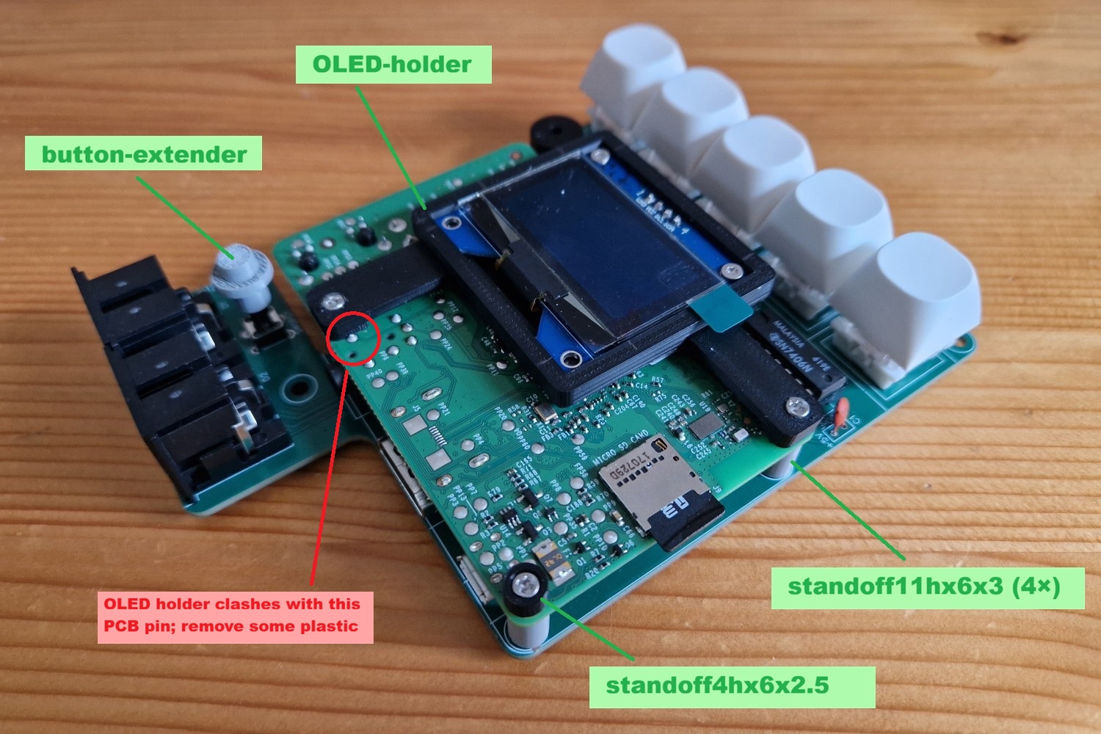
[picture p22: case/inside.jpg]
inside parts


- [OLED-holder stl file](OLED-holder.stl)  
  The OLED holder has a flaw: the top lip collides with a PCB pin; I removed some material with a soldering iron.    
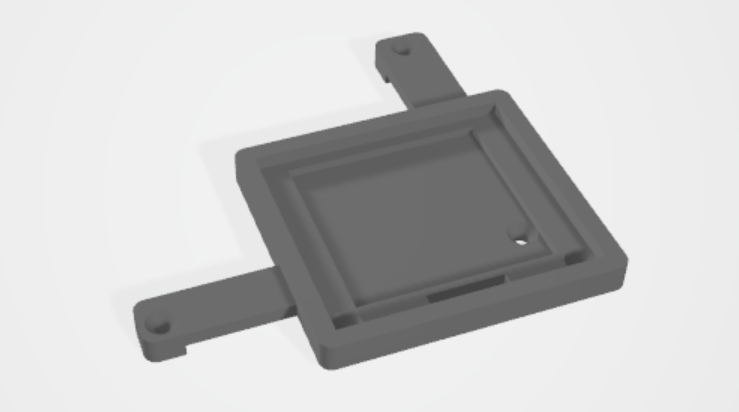
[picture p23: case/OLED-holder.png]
OLED-holder
  

- [button-extender stl file](button-extender.stl)  
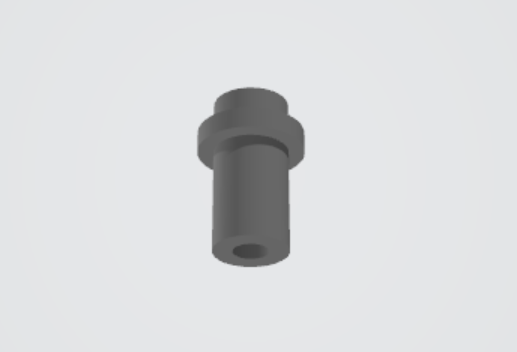
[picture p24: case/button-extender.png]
button-extender
  

- [standoff11hx6x3 stl file](standoff11hx6x3.stl) (needed four times)  
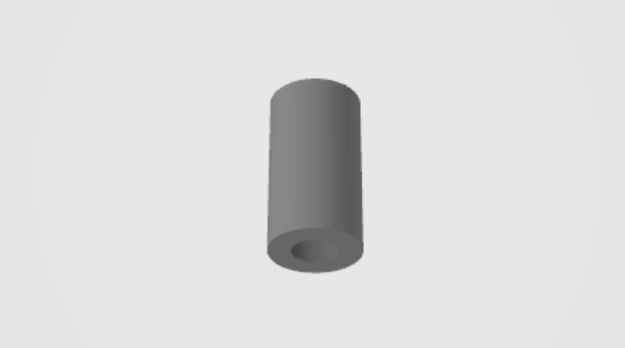
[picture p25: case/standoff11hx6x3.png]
standoff11hx6x3
  

- [standoff4hx6x2.5 stl file](standoff4hx6x2.5.stl)  
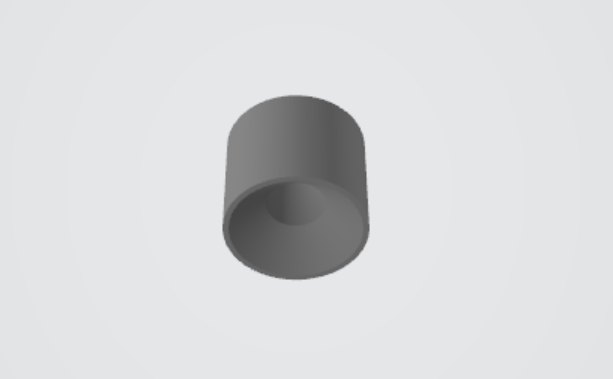
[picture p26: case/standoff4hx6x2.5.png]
standoff4hx6x2
  

## Gallery

Front top view

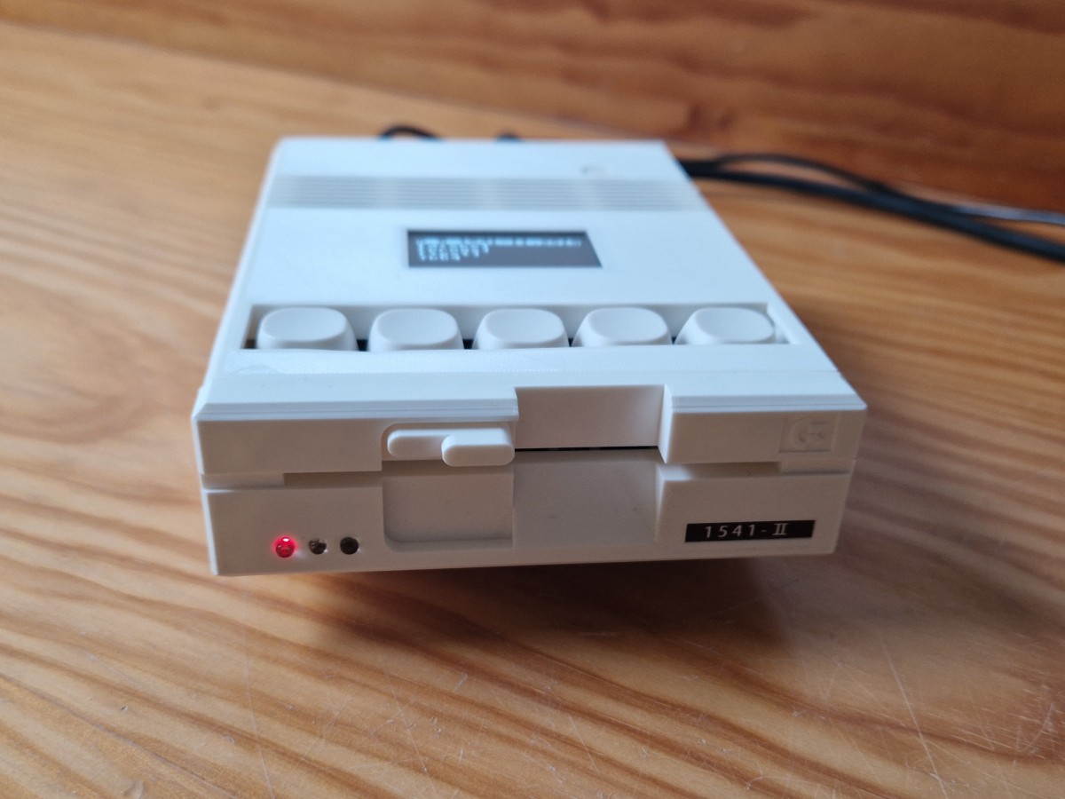
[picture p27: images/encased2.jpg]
Front view


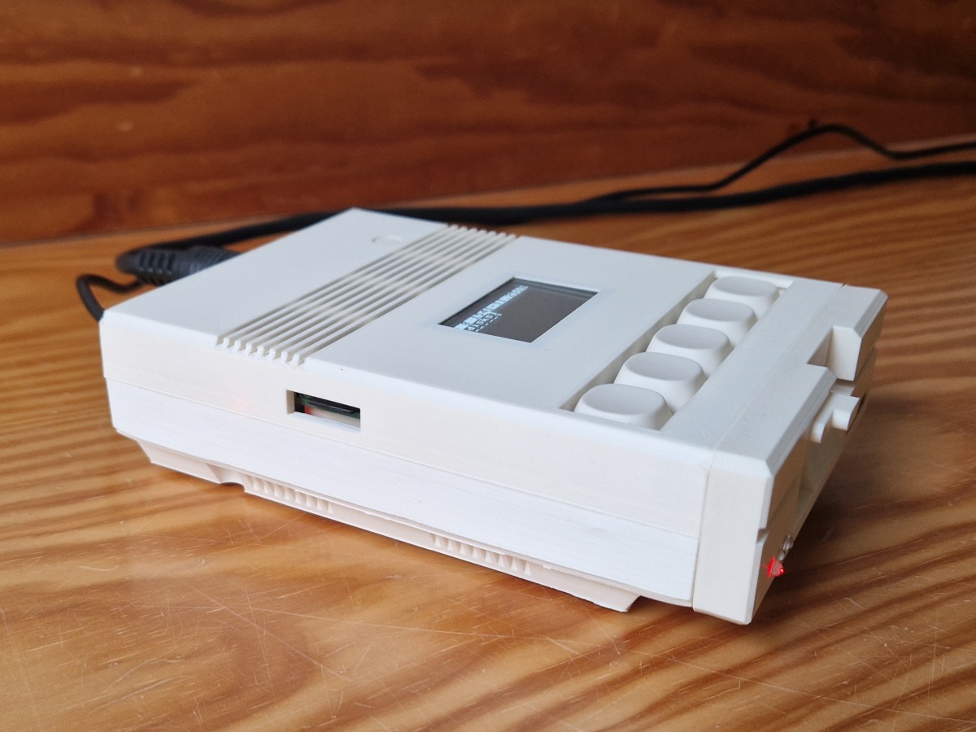
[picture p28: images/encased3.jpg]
SD card and foot


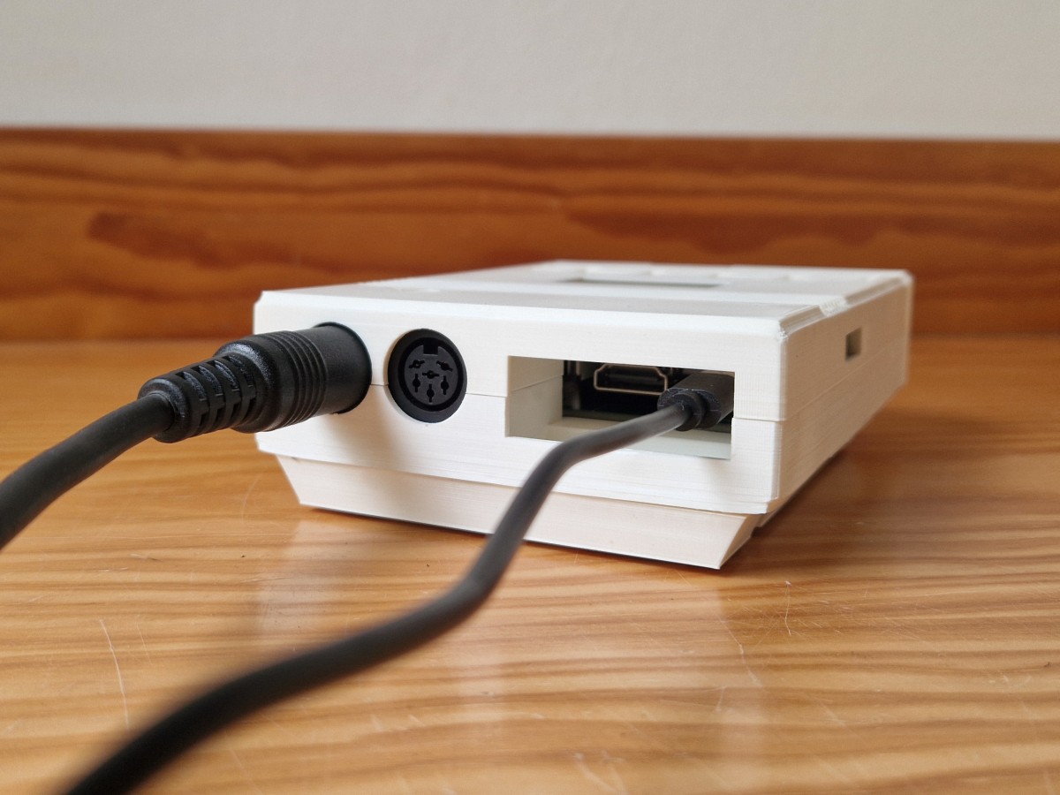
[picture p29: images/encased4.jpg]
Back with connectors


Pi1541 with real 1541-II

(end)

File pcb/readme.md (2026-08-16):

# PCB

The PCB design files for my Pi1541.

See the [main project page](https://github.com/maarten-pennings/pi1541device#my-design) 
for high level design choices.

## Sources

I designed the schematics and layout with [EasyEDA](https://easyeda.com/).

### Schematics

The schematics as [EasyEDA json](pi1541-schem.json) 
or as [pdf](pi1541-schem.pdf).

### Layout

The layout as [EasyEDA json](pi1541-pcb.json) 
or as [front pdf](pi1541-pcb-front.pdf) or [back pdf](pi1541-pcb-back.pdf).

### Gerber

The [gerber](pi1541_gerber.zip) file for [JLCPCB](https://jlcpcb.com/DMP).

## Renders

### Renders of the bare PCB

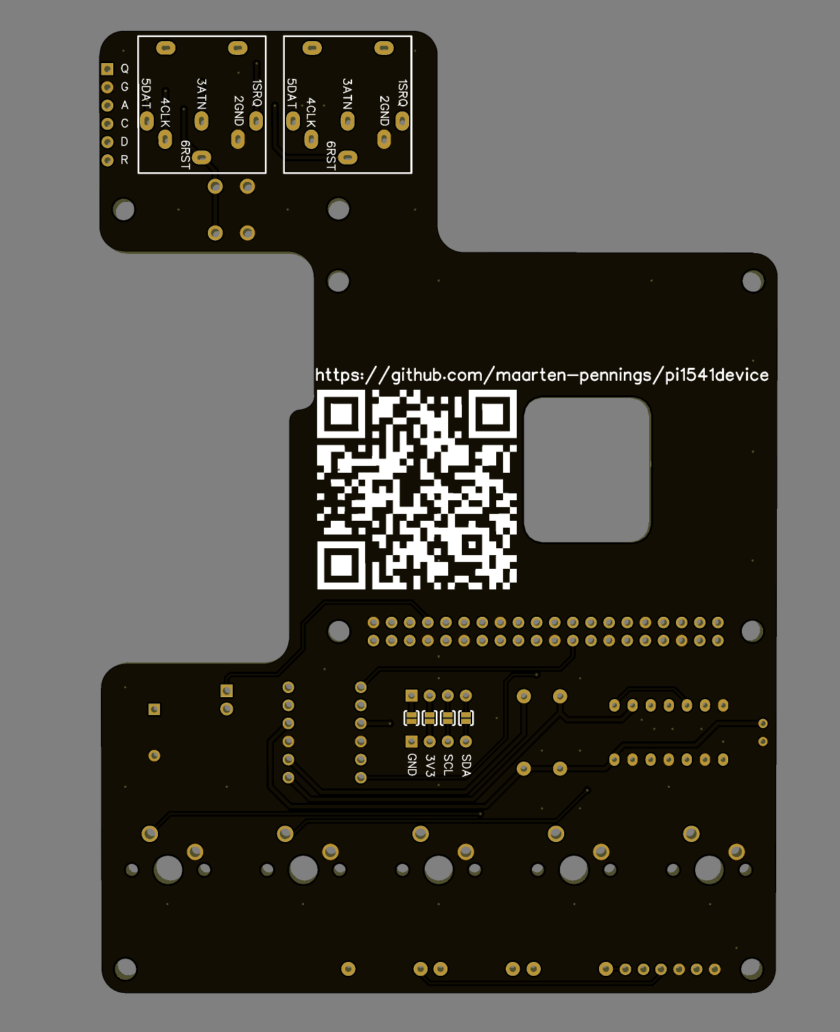
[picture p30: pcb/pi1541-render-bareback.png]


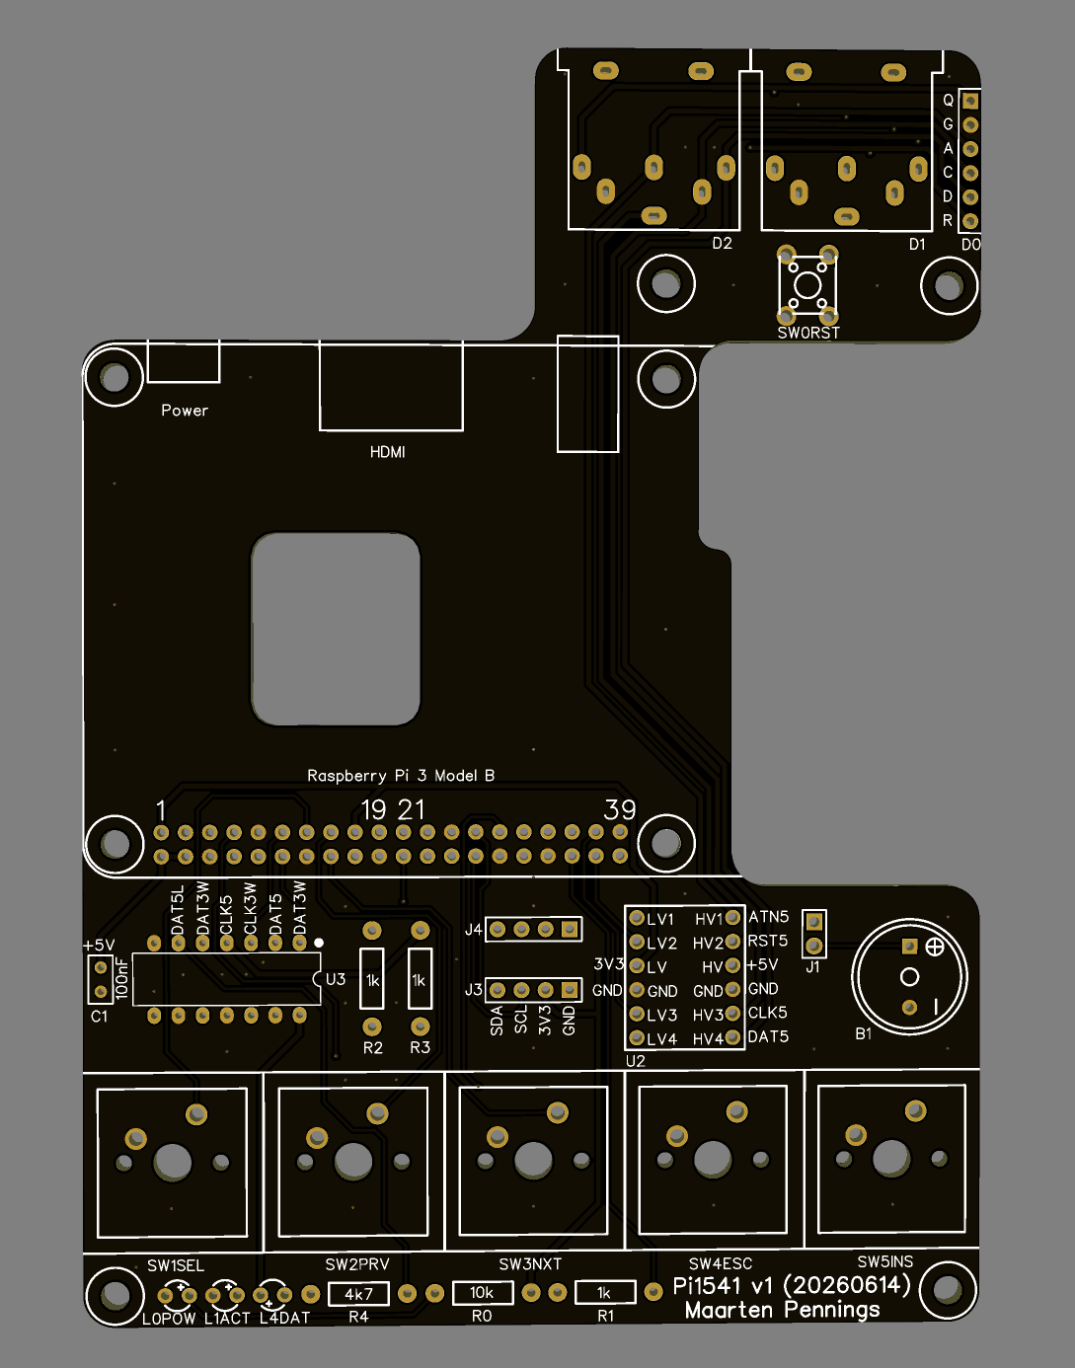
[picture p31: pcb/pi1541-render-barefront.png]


### Renders of assembled PCB

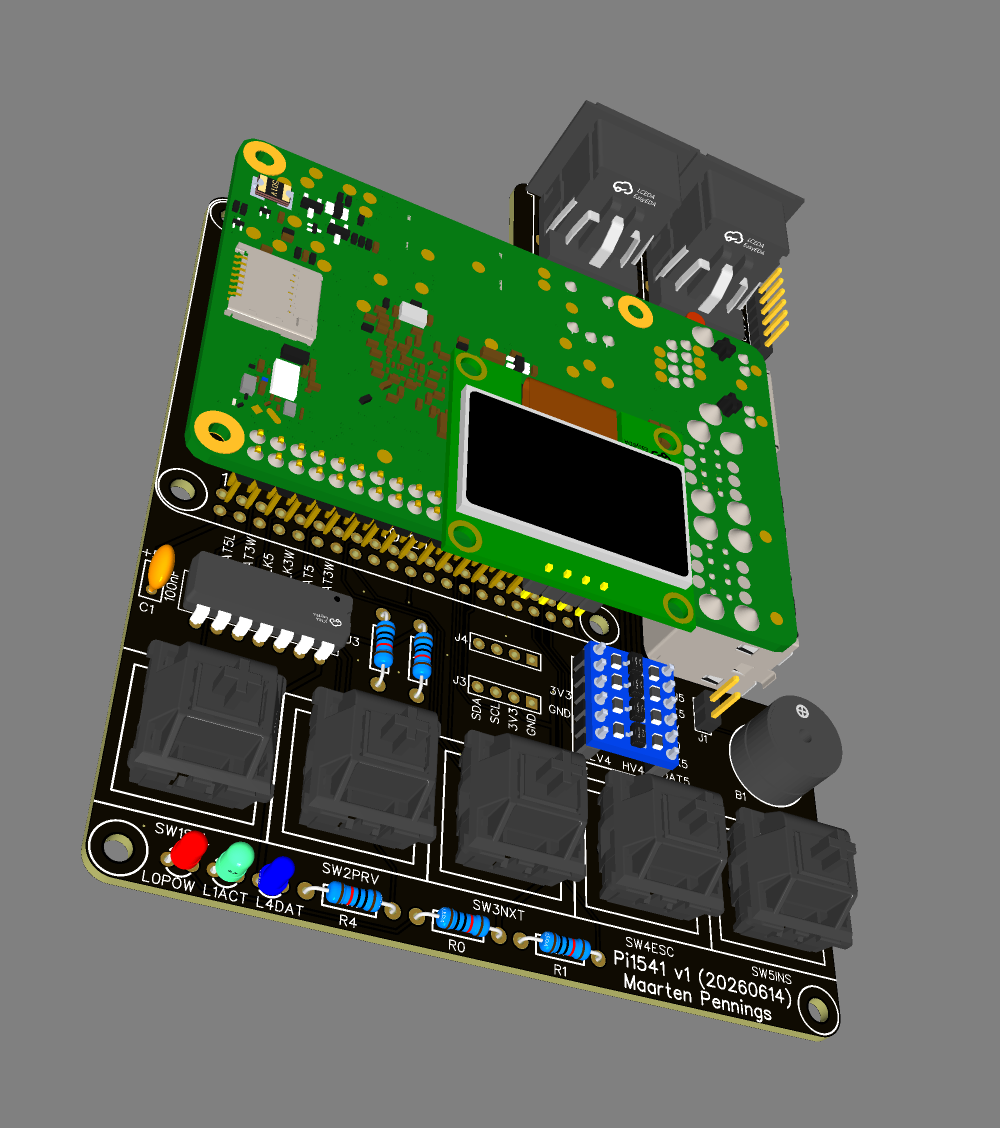
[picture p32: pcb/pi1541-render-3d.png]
Render 3D


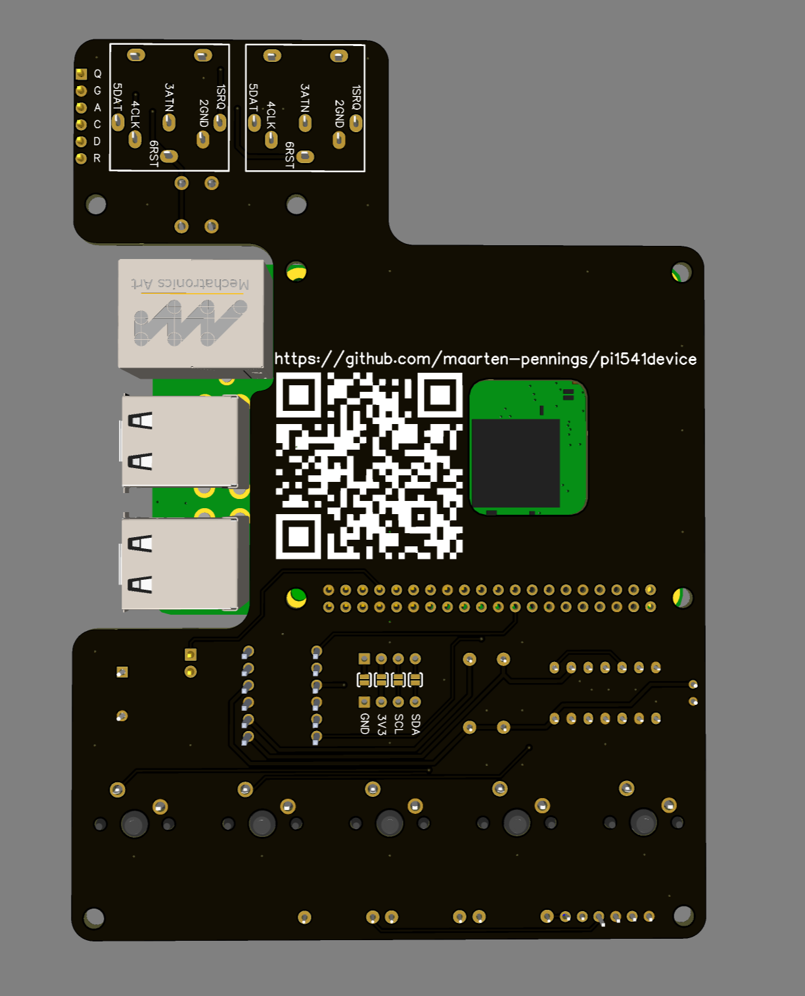
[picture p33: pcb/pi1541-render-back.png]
Render back side


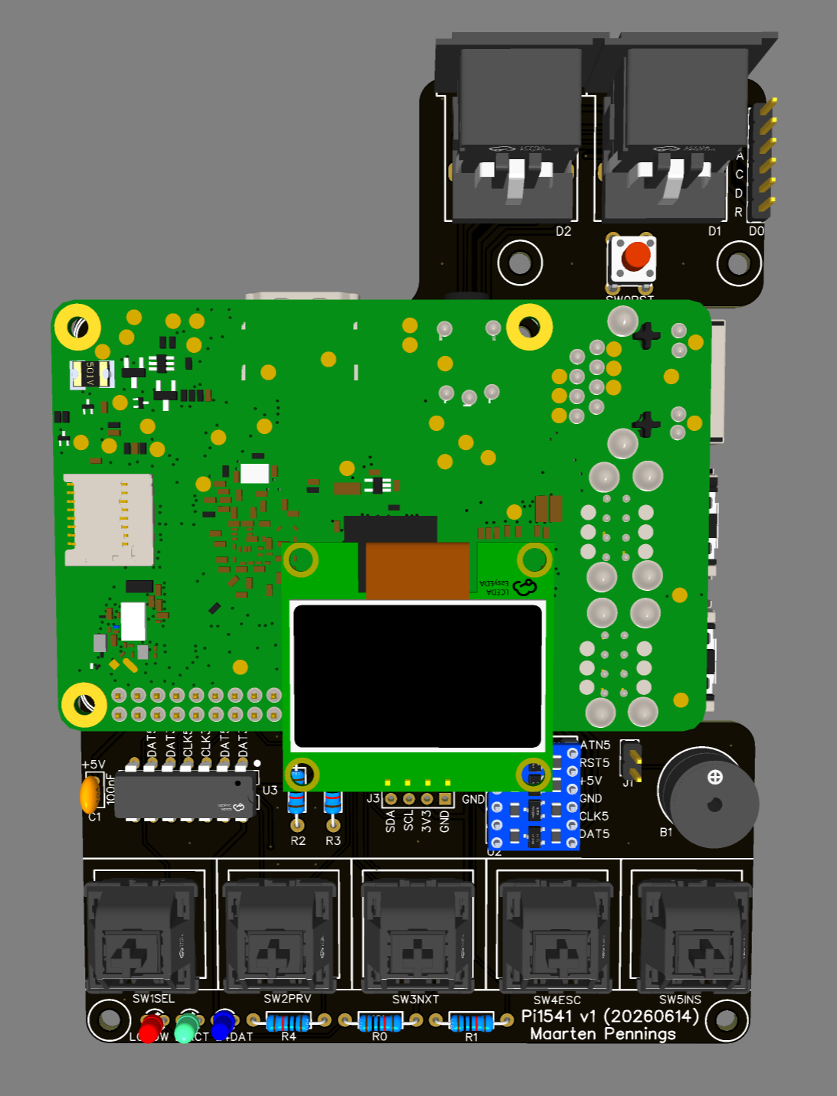
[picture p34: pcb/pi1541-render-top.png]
Render top


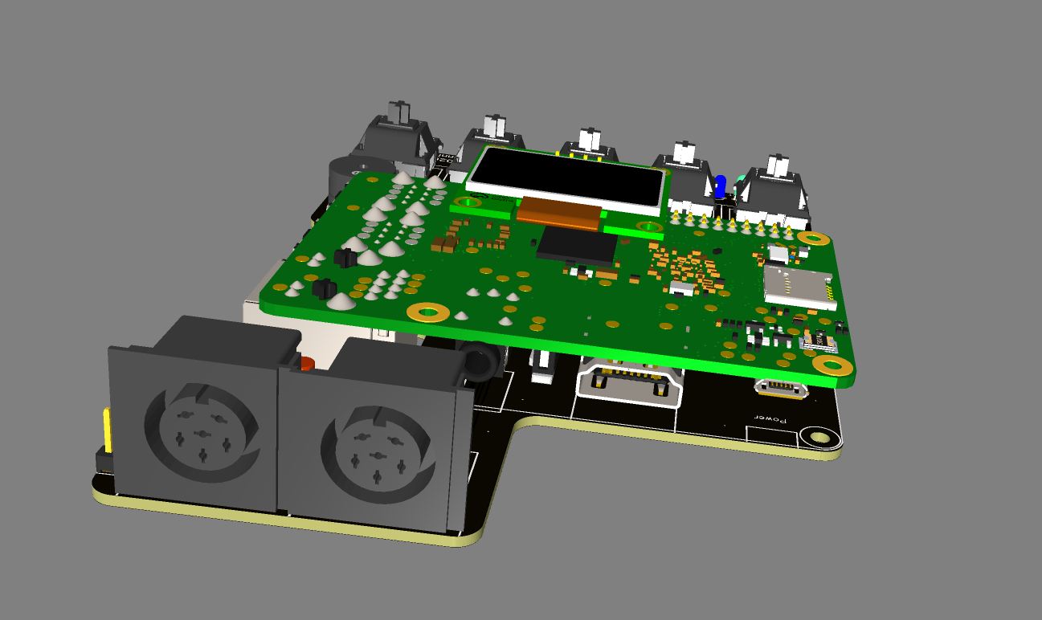
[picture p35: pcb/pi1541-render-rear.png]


## Gallery





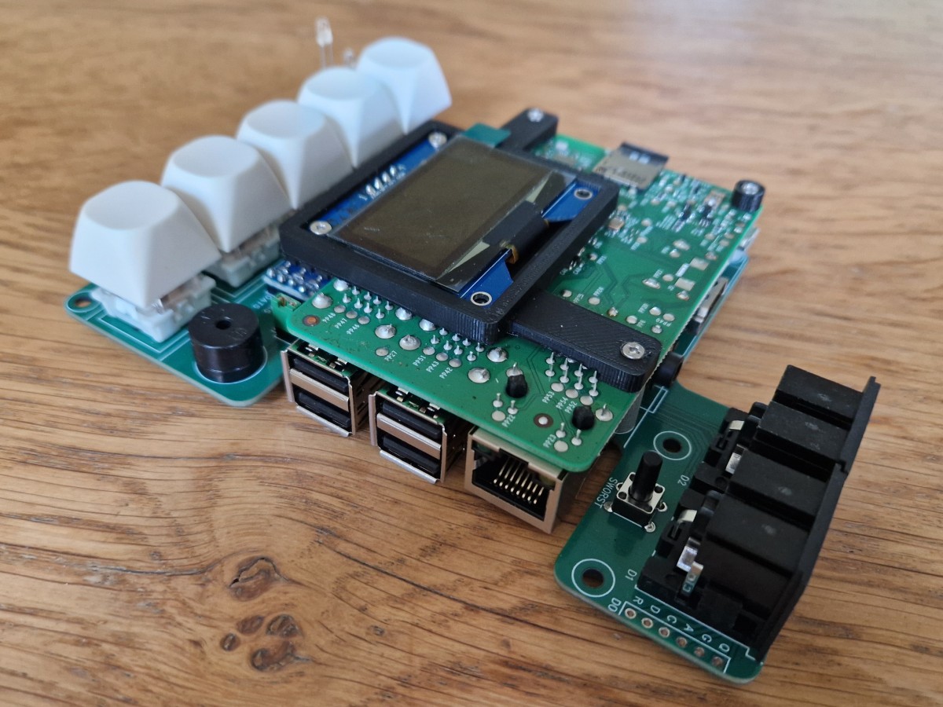
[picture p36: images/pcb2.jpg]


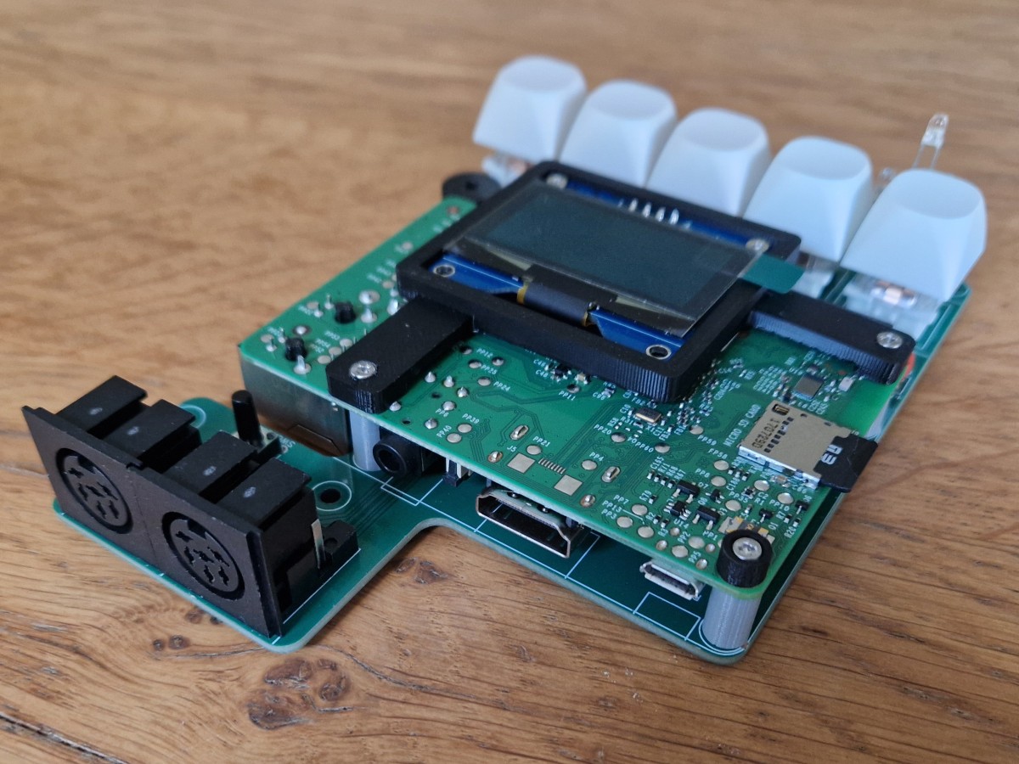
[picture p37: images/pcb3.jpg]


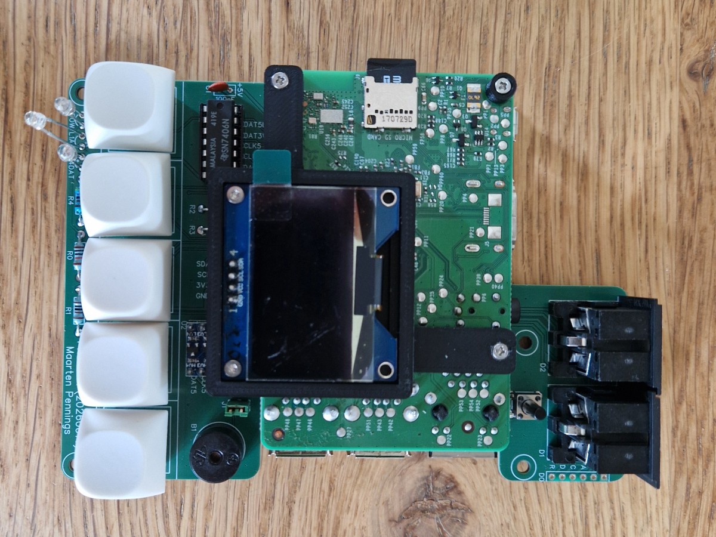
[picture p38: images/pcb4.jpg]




(end)

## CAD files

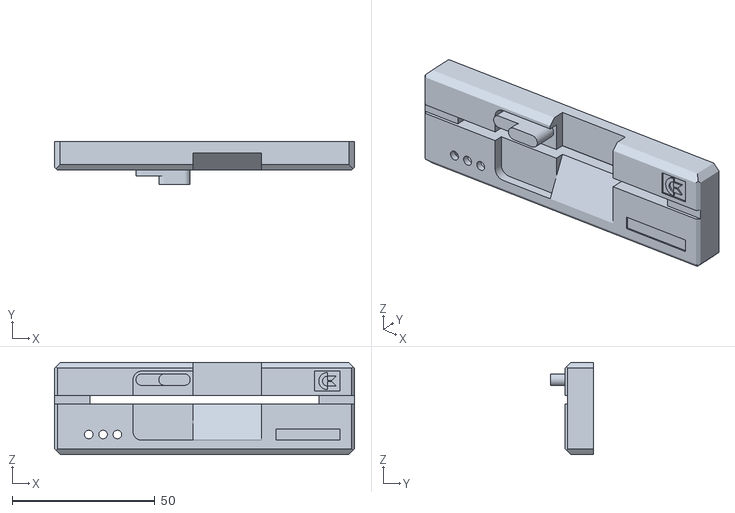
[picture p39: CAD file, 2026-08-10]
case/front.stl
105.0 x 15.0 x 32.2

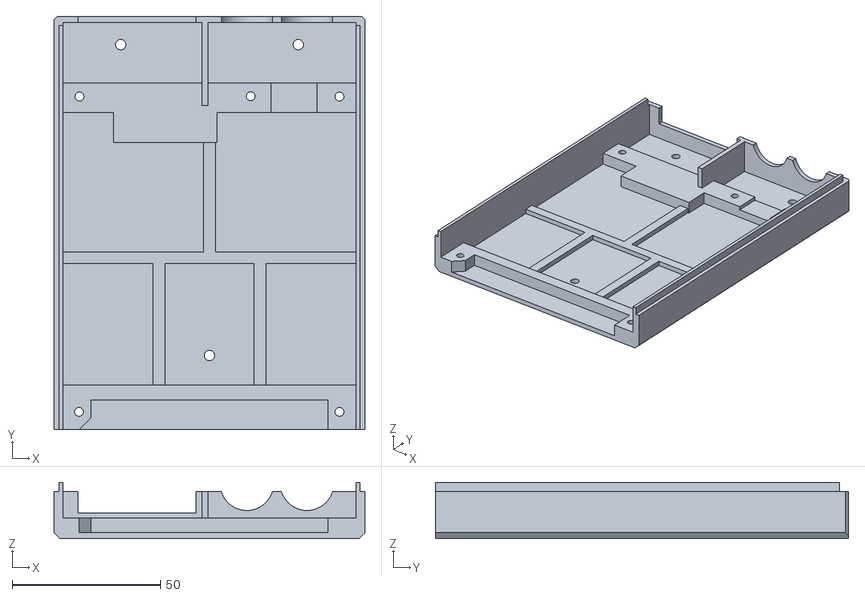
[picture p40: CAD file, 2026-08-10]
case/bot.stl
105.0 x 139.5 x 19.0

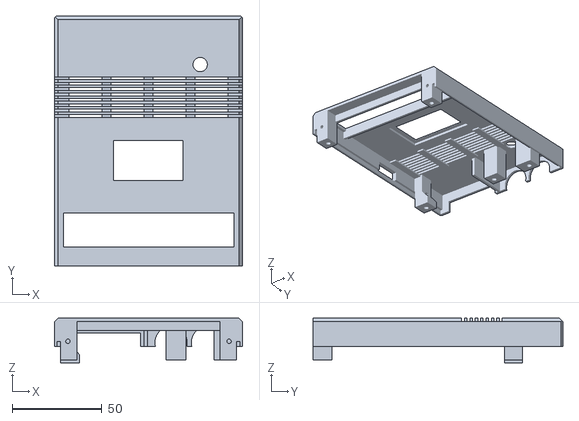
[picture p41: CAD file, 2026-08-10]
case/top.stl
105.0 x 139.5 x 25.1

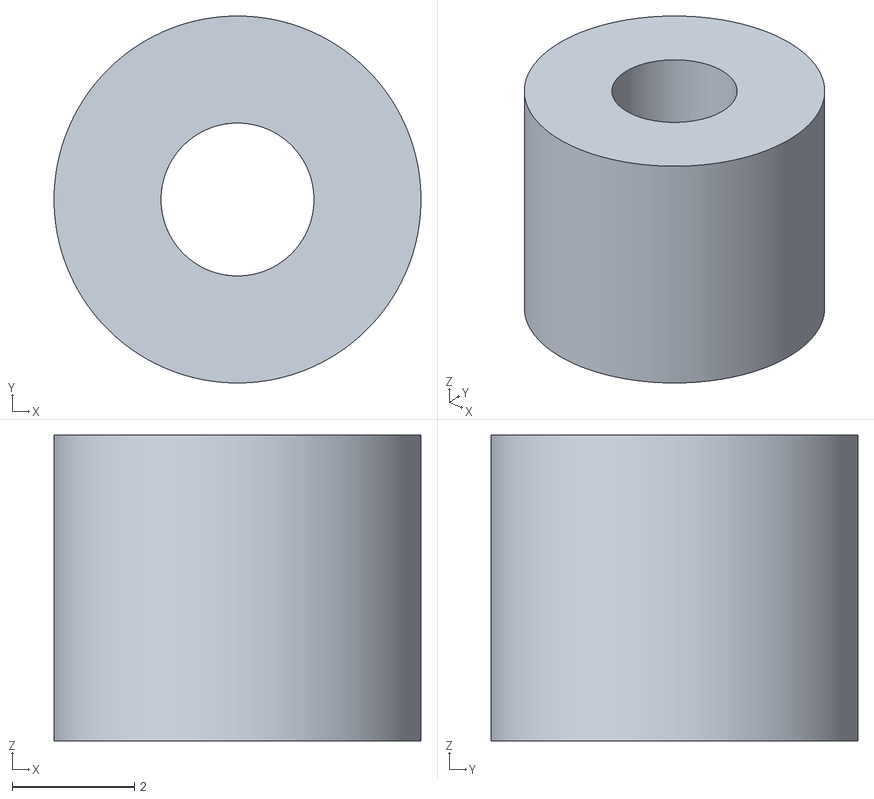
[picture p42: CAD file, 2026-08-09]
case/standoff4hx6x2.5.stl
6.00 x 6.00 x 5.00

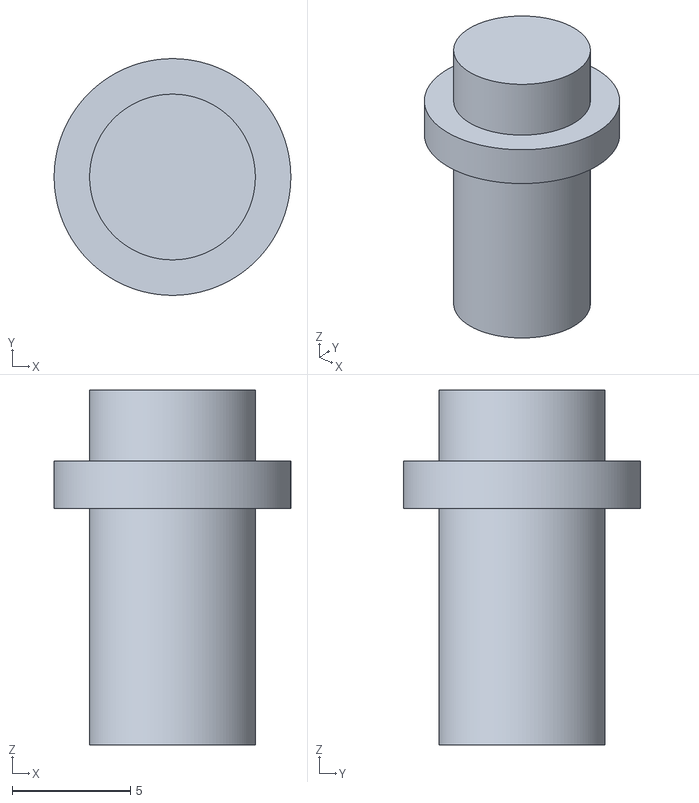
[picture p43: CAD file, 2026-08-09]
case/button-extender.stl
10.00 x 10.00 x 15.0

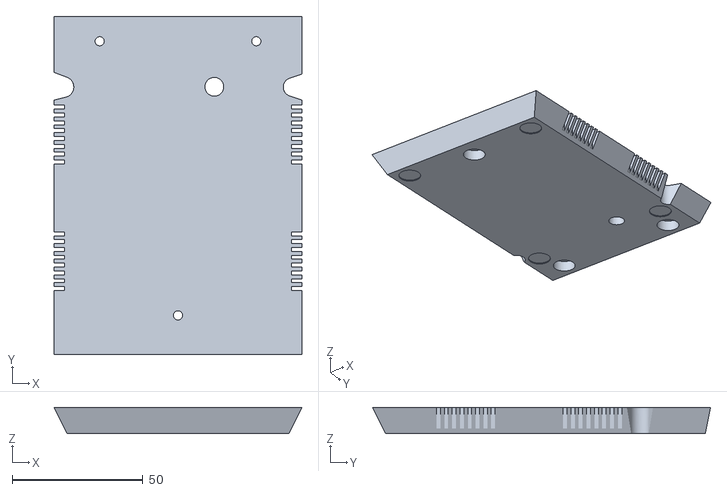
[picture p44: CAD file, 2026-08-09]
case/foot.stl
95.0 x 129.5 x 10.0

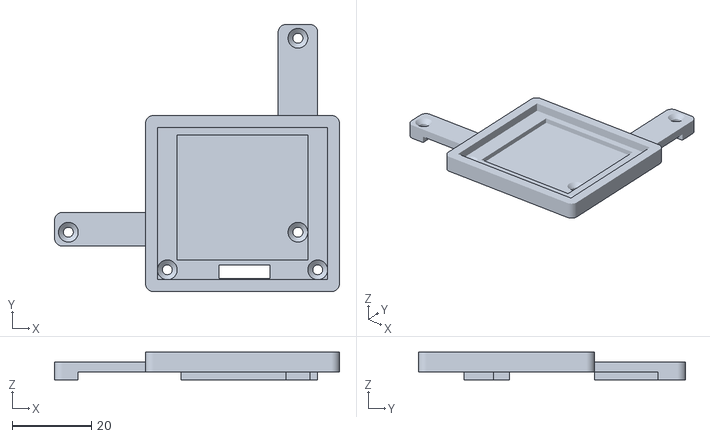
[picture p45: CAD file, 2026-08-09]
case/OLED-holder.stl
72.0 x 67.5 x 7.00

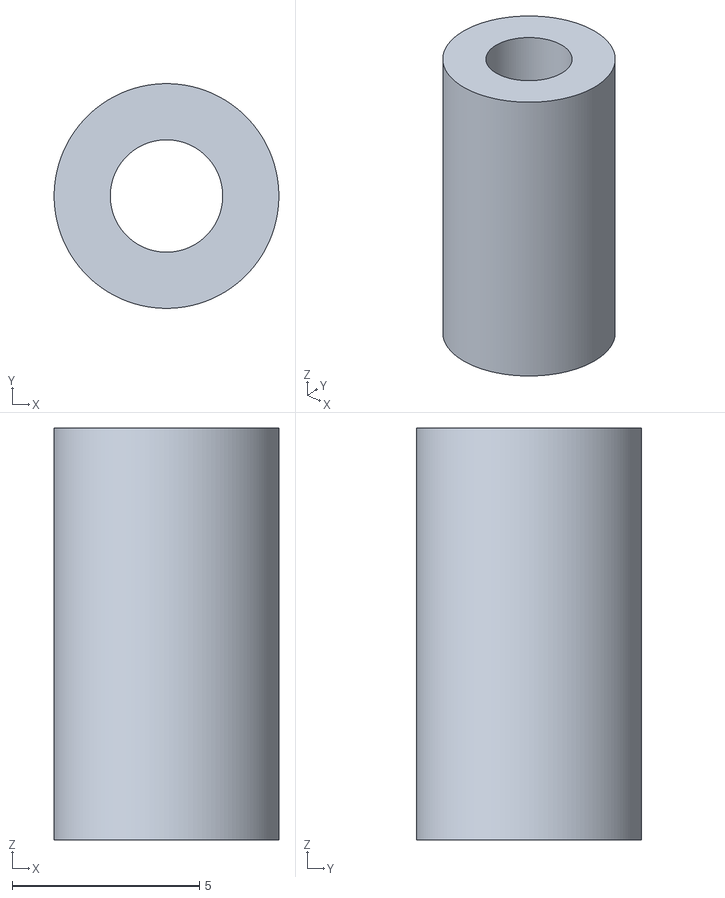
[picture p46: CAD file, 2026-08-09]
case/standoff11hx6x3.stl
6.00 x 6.00 x 11.0

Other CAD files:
case/bottom.stl

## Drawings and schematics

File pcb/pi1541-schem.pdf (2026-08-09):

3v3 +5V

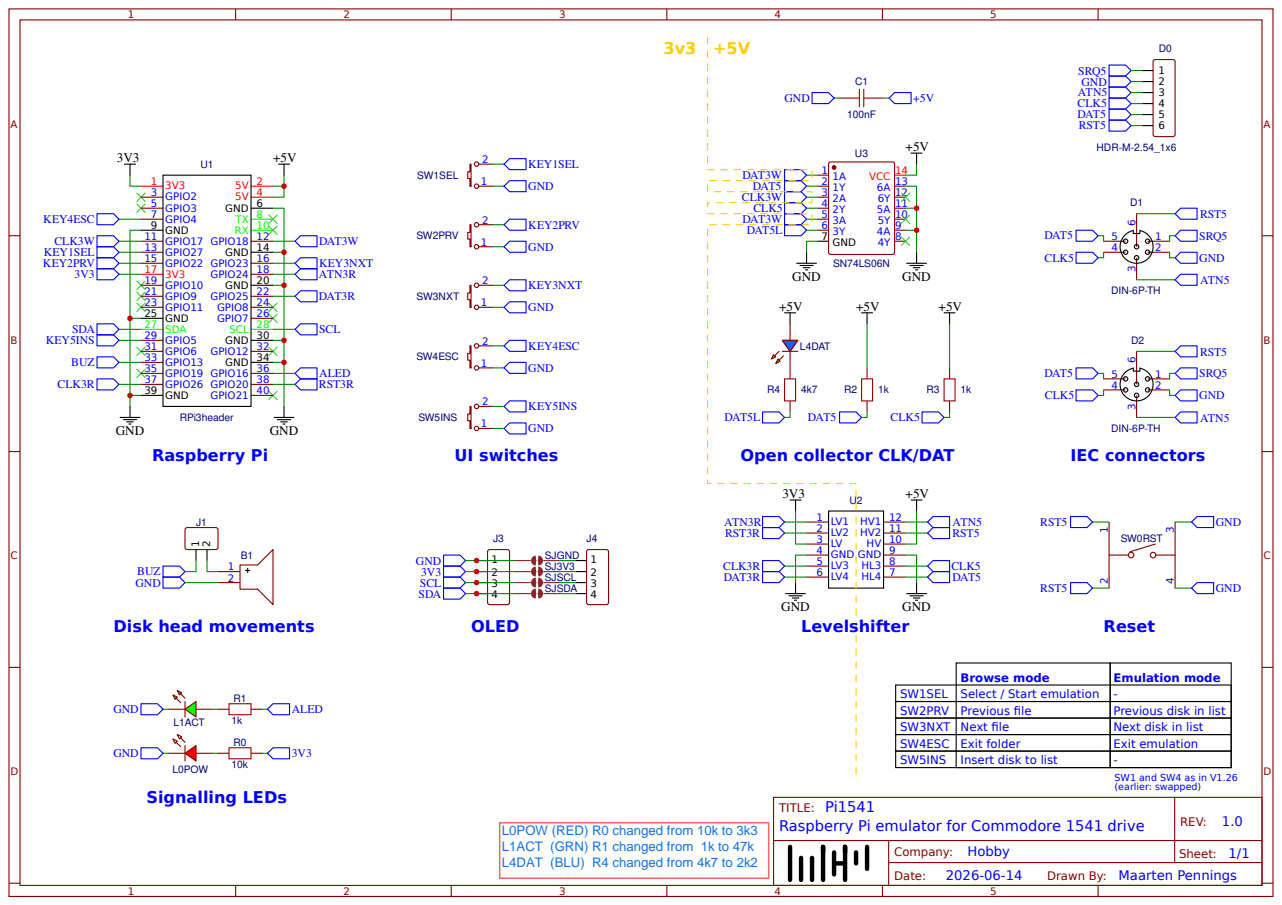
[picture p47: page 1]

Select / Start emulation
Previous file
Next file
Exit folder
Insert disk to list

Previous disk in list
Next disk in list
Exit emulation
SW1 and SW4 as in V1.26
(earlier: swapped)

Drawn By: Maarten Pennings

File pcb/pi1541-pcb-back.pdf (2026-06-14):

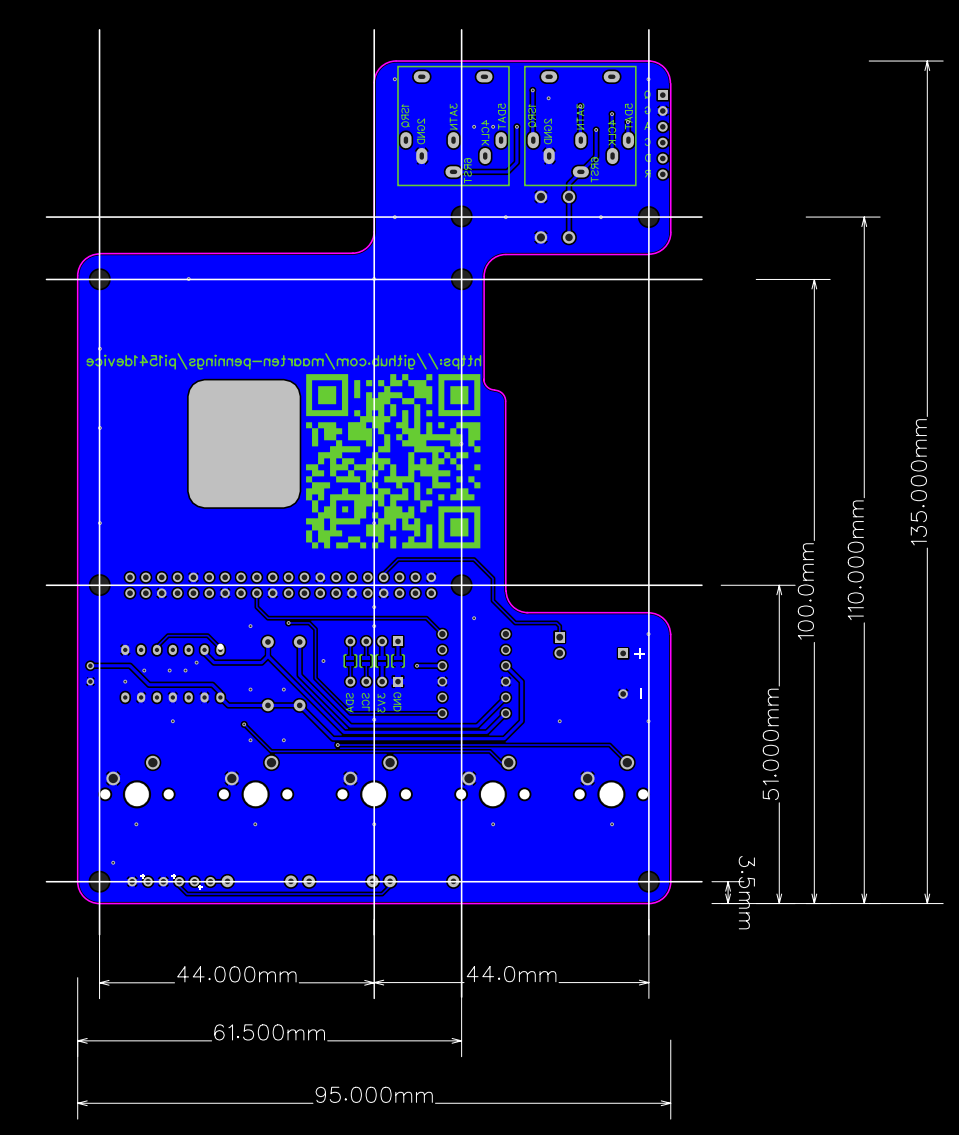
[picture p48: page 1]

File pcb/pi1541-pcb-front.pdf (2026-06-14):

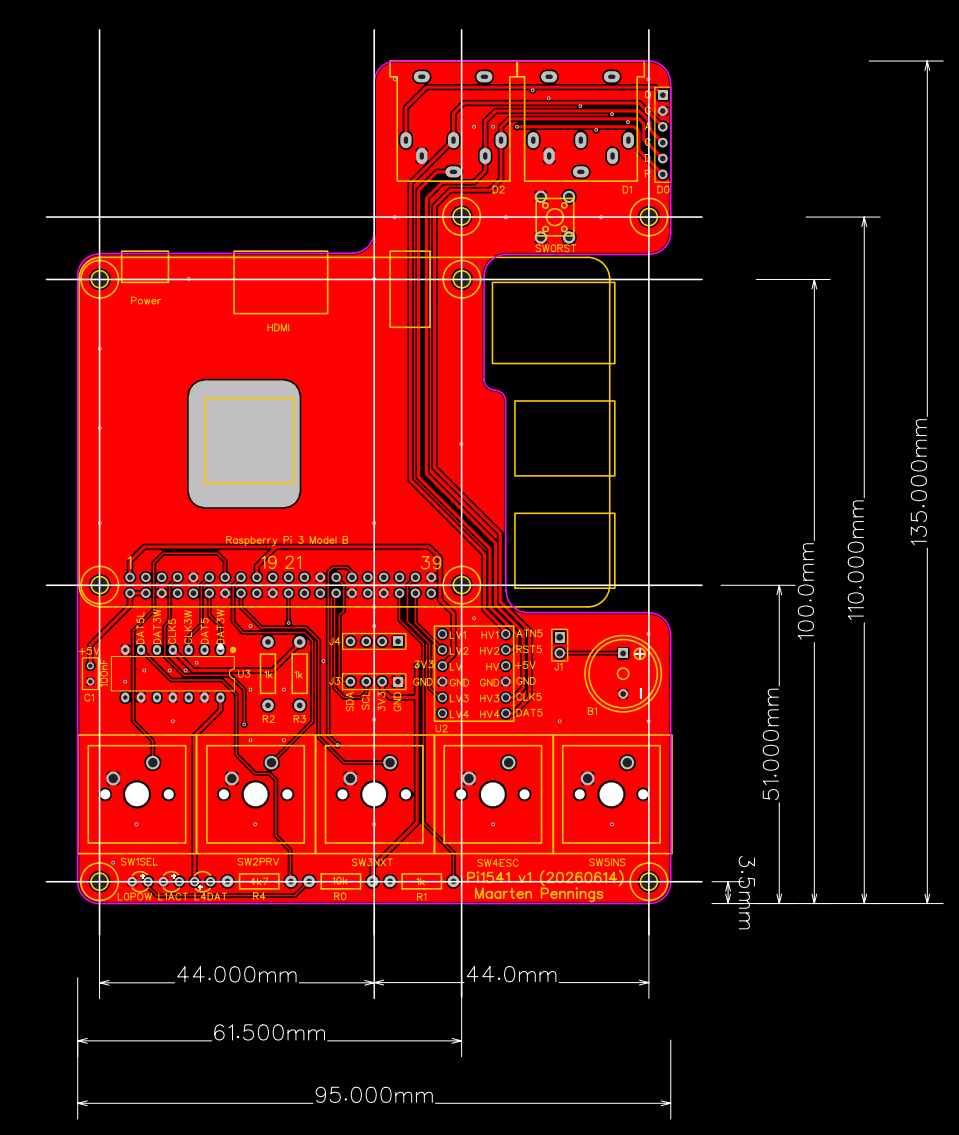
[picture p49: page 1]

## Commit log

2026-06-14 created pcb
2026-08-09 case added
    [OLED-holder.stl, bottom.stl, button-extender.stl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]
2026-08-10 With chamfer
    [bot.stl, front.stl, top.stl]
2026-08-16 added pcb
2026-08-16 added case
